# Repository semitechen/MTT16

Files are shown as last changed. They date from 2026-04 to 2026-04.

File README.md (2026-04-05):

**⚠️WARNING⚠️**  
This is a "Work in progress" project.
Read all the documentation before proceeding with development.

# Hardware Tracker MIDI Sequencer

A hardware-style MIDI sequencer designed for DJs and home producers. This device combines tactile control with powerful features to streamline music creation and performance.

---

## Features

### 🎵 Tracks & MIDI Control
- **16 Tracks**: Each track consists of 4 bytes:  
  - **Byte 1**: Type and channel  
  - **Byte 2**: Data byte 1 (note) 
  - **Byte 3**: Data byte 2 (velocity)
  - **Byte 4**: Delay  
- **Editing**: Tracks can be edited and muted via dedicated keypads.

### 🔄 Magnetic Encoder & Sync Control
- **Magnetic Encoder**:  
  - Control track position.  
  - Sync with song tempo "vinyl style".  
  - **Shift Key** under the encoder for alternate functions.  

### 🎚️ Tempo Control
- **Tempo Fader**: Fine-tune playback tempo.  
- **Tempo Modes**:  
  - Select tempo control range (+8, +16, wide) via buttons and LED indicators.

### ⌨️ Keypads & Modes
#### 16-Key Cherry MX Keypad
- **Modes**:  
  - Edit mode (upcoming functionality).  
  - Mute mode: Mute individual tracks.

#### 8-Key Cherry MX Keypad 
| Key | Shift Function | 
|---|---|
| Cue | Play |
| A | Edit |
| B | Mute |
| Scene | New Scene |
| Nudge | Tempo |
| Copy | Paste |
| Delete | Undo |
| OK | Duplicate |

### 📟 Display
- **8x32 7-Segment LED Display**:  
  - Each character is 0.28".  
  - Displays key information across 4 columns in Scene Mode:  
    - Original tempo  
    - Scene  
    - A track  
    - B track  

### 🎛️ Scene Mode
- Use **OK Key** to select a scene and assign it to **Track A** or **Track B** via the **A** and **B** keys.  
- Each scene comprises 16 editable tracks.  
- Select and edit tracks using the **16-Key Keypad** in Edit Mode.  

---

## 📸 Photos
_Add photos here._  

---

## License
This project is licensed under the [Creative Commons Attribution-NonCommercial-ShareAlike 4.0 International License](https://creativecommons.org/licenses/by-nc-sa/4.0/).  

- You are free to build and modify the hardware and software for **non-commercial purposes**.  
- Commercial use of this project is strictly prohibited.

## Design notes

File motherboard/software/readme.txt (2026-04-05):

To program the motherboard (pcb with RP2040 chip), first put the device into divice mode,
then connect the board to the computer using the usb-c port.

Pico sdk should be installed, if you haven't added the --recursive flag while cloning the repo run:
git submodule update --init

To build run the following commands:
mkdir build
cd build
cmake ..
make -j4

Then to flash, inside the build folder, run:
make flash

If this doesn't work:
Hold the usb-boot button while plugging in the usb.
Then copy the motherboard.uf2 file, located in the build folder, to RP2040 external storage device.

The circuit located on the board is pretty much identical to the Rasberry Pi Pico,
so the usage should be the same, apart from the differences caused by the use of usb-c (device mode).

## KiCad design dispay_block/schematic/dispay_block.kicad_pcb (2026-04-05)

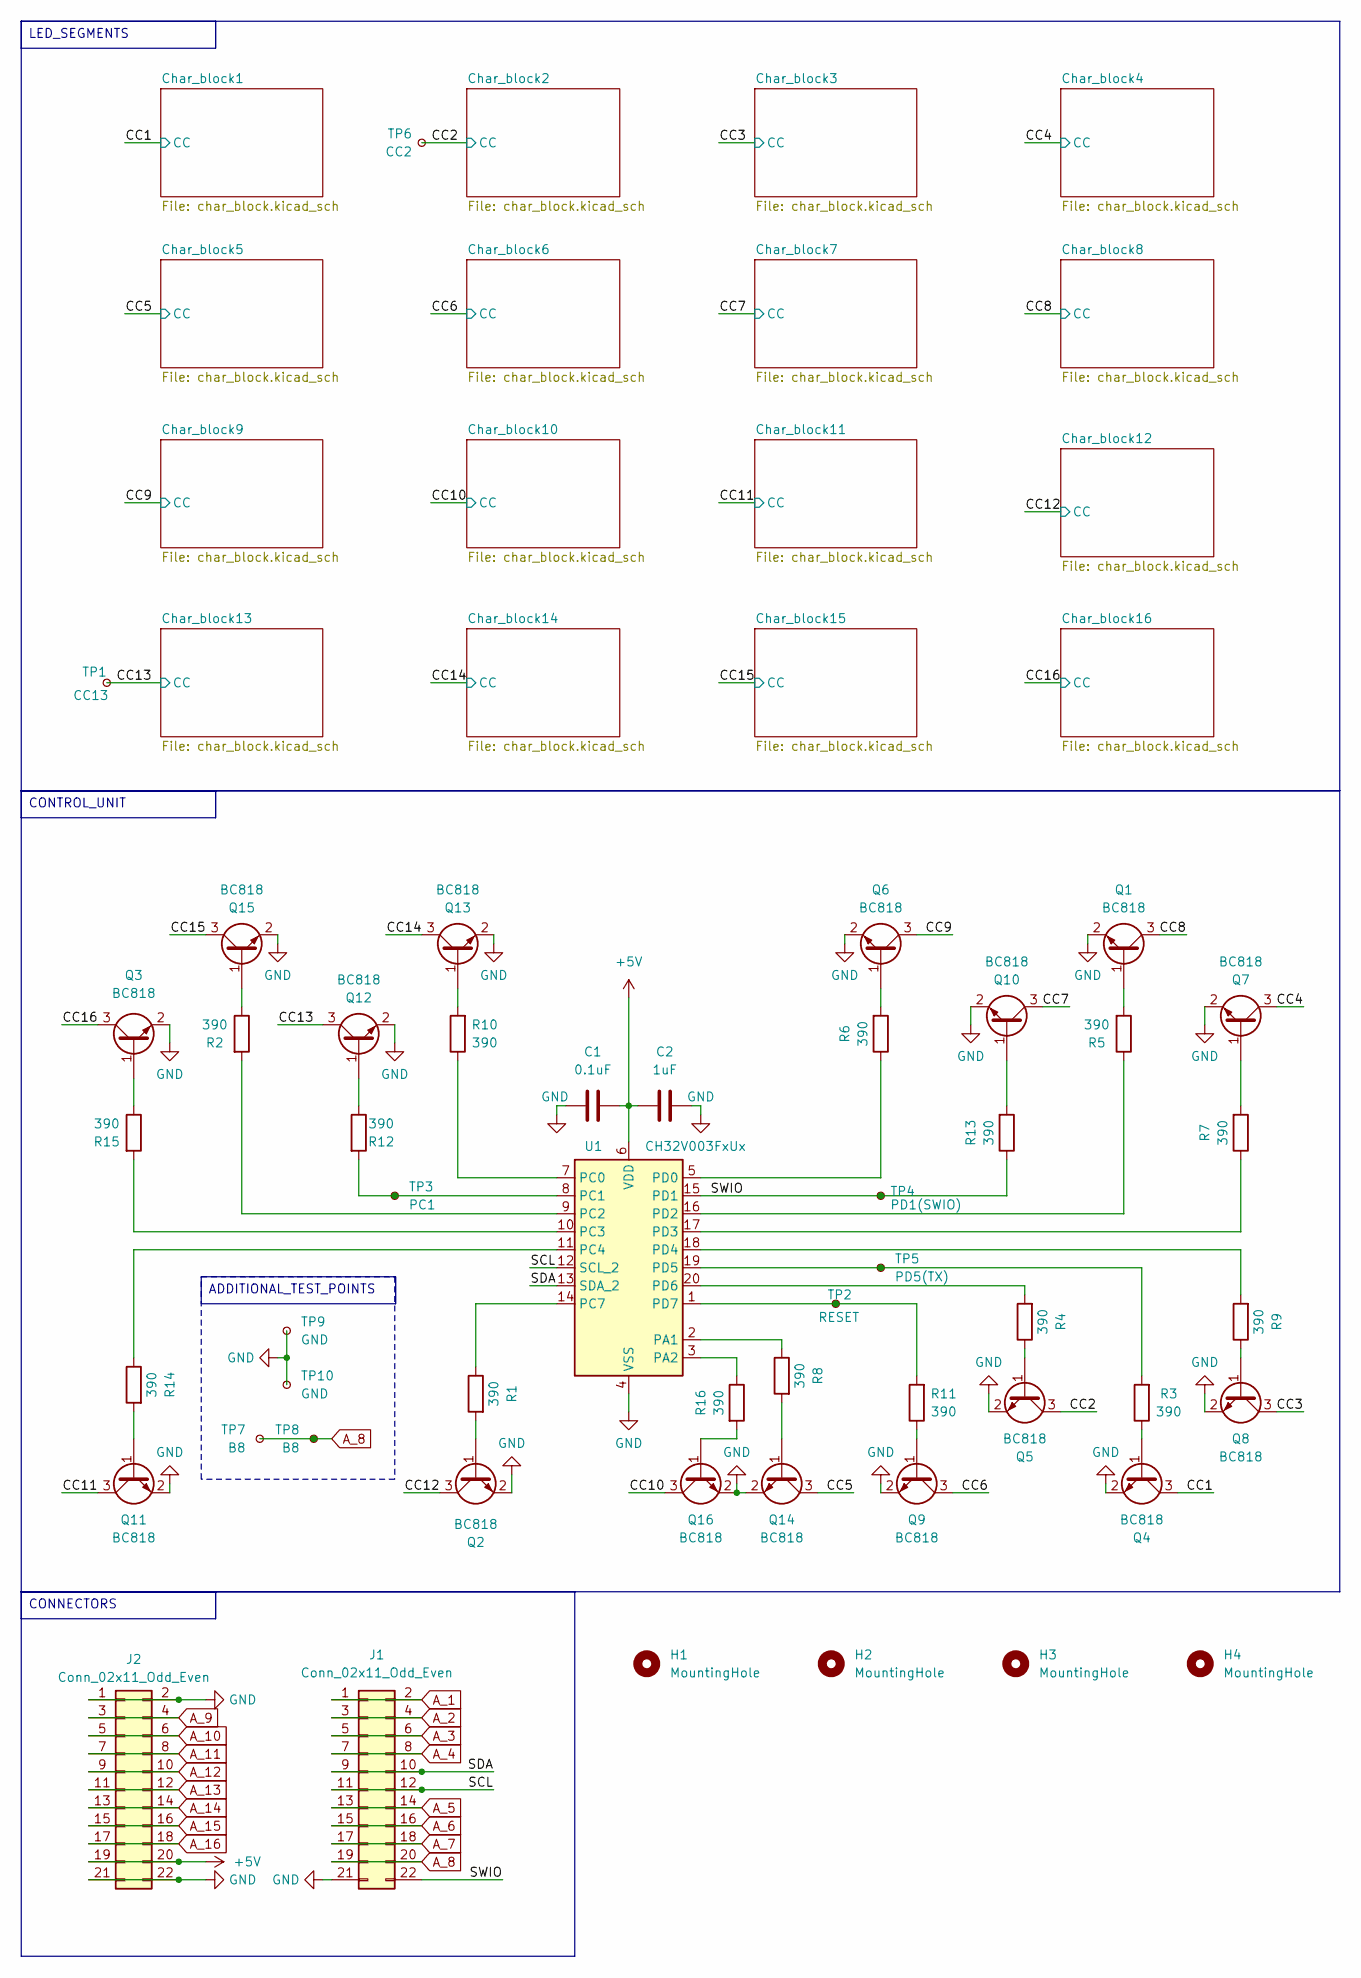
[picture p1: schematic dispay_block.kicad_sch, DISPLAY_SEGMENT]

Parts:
C1: 0.1uF; C_0603_1608Metric
C2: 1uF; C_0603_1608Metric
H1, H2, H3, H4: MountingHole; MountingHole_3.2mm_M3
J1, J2: Conn_02x11_Odd_Even; PinHeader_2x11_P2.54mm_Vertical
Q1, Q2, Q3, Q4, Q5, Q6, Q7, Q8, Q9, Q10, Q11, Q12, Q13, Q14, Q15, Q16: BC818; SOT-23
R1, R2, R3, R4, R5, R6, R7, R8, R9, R10, R11, R12, R13, R14, R15, R16: 390; R_0603_1608Metric
TP1: CC13; TestPoint_Pad_D1.5mm
TP2: RESET; TestPoint_Pad_D1.5mm
TP3: PC1; TestPoint_Pad_D1.5mm
TP4: PD1(SWIO); TestPoint_Pad_D1.5mm
TP5: PD5(TX); TestPoint_Pad_D1.5mm
TP6: CC2; TestPoint_Pad_D1.5mm
TP7, TP8: B8; TestPoint_Pad_D1.5mm
TP9, TP10: GND; TestPoint_Pad_D1.0mm
U1: CH32V003FxUx; QFN-20-1EP_3x3mm_P0.4mm_EP1.65x1.65mm

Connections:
+5V: C1.2, C2.2, J2.19, J2.20, U1.6 (VDD)
/CC1: Q4.3 (C); also elsewhere on the board
/CC2: Q5.3 (C), TP6.1; also elsewhere on the board
/CC3: Q8.3 (C); also elsewhere on the board
/CC4: Q7.3 (C); also elsewhere on the board
/CC5: Q14.3 (C); also elsewhere on the board
/CC6: Q9.3 (C); also elsewhere on the board
/CC7: Q10.3 (C); also elsewhere on the board
/CC8: Q1.3 (C); also elsewhere on the board
/CC9: Q6.3 (C); also elsewhere on the board
/CC10: Q16.3 (C); also elsewhere on the board
/CC11: Q11.3 (C); also elsewhere on the board
/CC12: Q2.3 (C); also elsewhere on the board
/CC13: Q12.3 (C), TP1.1; also elsewhere on the board
/CC14: Q13.3 (C); also elsewhere on the board
/CC15: Q15.3 (C); also elsewhere on the board
/CC16: Q3.3 (C); also elsewhere on the board
/SCL: J1.11, J1.12, U1.12 (SCL_2)
/SDA: J1.9, J1.10, U1.13 (SDA_2)
/SWIO: J1.22, R13.1, TP4.1, U1.15 (PD1)
A_1: J1.1, J1.2; also elsewhere on the board
A_2: J1.3, J1.4; also elsewhere on the board
A_3: J1.5, J1.6; also elsewhere on the board
A_4: J1.7, J1.8; also elsewhere on the board
A_5: J1.13, J1.14; also elsewhere on the board
A_6: J1.15, J1.16; also elsewhere on the board
A_7: J1.17, J1.18; also elsewhere on the board
A_8: J1.19, J1.20, TP7.1, TP8.1; also elsewhere on the board
A_9: J2.3, J2.4; also elsewhere on the board
A_10: J2.5, J2.6; also elsewhere on the board
A_11: J2.7, J2.8; also elsewhere on the board
A_12: J2.9, J2.10; also elsewhere on the board
A_13: J2.11, J2.12; also elsewhere on the board
A_14: J2.13, J2.14; also elsewhere on the board
A_15: J2.15, J2.16; also elsewhere on the board
A_16: J2.17, J2.18; also elsewhere on the board
GND: C1.1, C2.1, J1.21, J2.1, J2.2, J2.21, J2.22, Q1.2 (E), Q2.2 (E), Q3.2 (E), Q4.2 (E), Q5.2 (E), Q6.2 (E), Q7.2 (E), Q8.2 (E), Q9.2 (E), Q10.2 (E), Q11.2 (E), Q12.2 (E), Q13.2 (E), Q14.2 (E), Q15.2 (E), Q16.2 (E), TP9.1, TP10.1, U1.4 (VSS), U1.21 (VSS)
unnamed: Q1.1 (B), R5.2
unnamed: Q2.1 (B), R1.2
unnamed: Q3.1 (B), R15.1
unnamed: Q4.1 (B), R3.1
unnamed: Q5.1 (B), R4.1
unnamed: Q6.1 (B), R6.2
unnamed: Q7.1 (B), R7.2
unnamed: Q8.1 (B), R9.1
unnamed: Q9.1 (B), R11.1
unnamed: Q10.1 (B), R13.2
unnamed: Q11.1 (B), R14.2
unnamed: Q12.1 (B), R12.1
unnamed: Q13.1 (B), R10.2
unnamed: Q14.1 (B), R8.2
unnamed: Q15.1 (B), R2.1
unnamed: Q16.1 (B), R16.2
unnamed: R8.1, U1.2 (PA1)
unnamed: R16.1, U1.3 (PA2)
unnamed: R10.1, U1.7 (PC0)
unnamed: R12.2, TP3.1, U1.8 (PC1)
unnamed: R2.2, U1.9 (PC2)
unnamed: R15.2, U1.10 (PC3)
unnamed: R14.1, U1.11 (PC4)
unnamed: R1.1, U1.14 (PC7)
unnamed: R6.1, U1.5 (PD0)
unnamed: R5.1, U1.16 (PD2)
unnamed: R7.1, U1.17 (PD3)
unnamed: R9.2, U1.18 (PD4)
unnamed: R3.2, TP5.1, U1.19 (PD5)
unnamed: R4.2, U1.20 (PD6)
unnamed: R11.2, TP2.1, U1.1 (PD7)

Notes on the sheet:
LED_SEGMENTS
CONTROL_UNIT
CONNECTORS
ADDITIONAL_TEST_POINTS

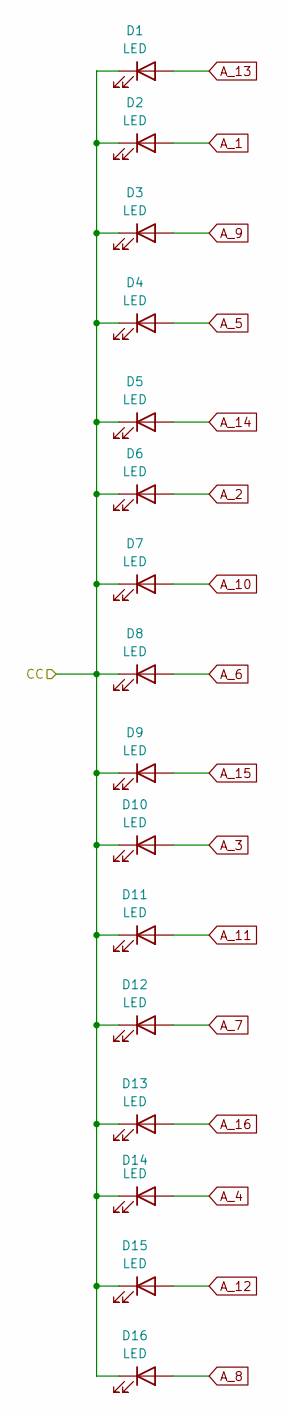
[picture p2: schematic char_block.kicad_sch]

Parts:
D1, D2, D3, D4, D5, D6, D7, D8, D9, D10, D11, D12, D13, D14, D15, D16: LED; LED_0603_1608Metric

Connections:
/CC1: D1.1 (K), D2.1 (K), D3.1 (K), D4.1 (K), D5.1 (K), D6.1 (K), D7.1 (K), D8.1 (K), D9.1 (K), D10.1 (K), D11.1 (K), D12.1 (K), D13.1 (K), D14.1 (K), D15.1 (K), D16.1 (K); also elsewhere on the board
A_1: D2.2 (A); also elsewhere on the board
A_2: D6.2 (A); also elsewhere on the board
A_3: D10.2 (A); also elsewhere on the board
A_4: D14.2 (A); also elsewhere on the board
A_5: D4.2 (A); also elsewhere on the board
A_6: D8.2 (A); also elsewhere on the board
A_7: D12.2 (A); also elsewhere on the board
A_8: D16.2 (A); also elsewhere on the board
A_9: D3.2 (A); also elsewhere on the board
A_10: D7.2 (A); also elsewhere on the board
A_11: D11.2 (A); also elsewhere on the board
A_12: D15.2 (A); also elsewhere on the board
A_13: D1.2 (A); also elsewhere on the board
A_14: D5.2 (A); also elsewhere on the board
A_15: D9.2 (A); also elsewhere on the board
A_16: D13.2 (A); also elsewhere on the board

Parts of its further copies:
D17, D18, D19, D20, D21, D22, D23, D24, D25, D26, D27, D28, D29, D30, D31, D32, D33, D34, D35, D36, D37, D38, D39, D40, D41, D42, D43, D44, D45, D46, D47, D48, D49, D50, D51, D52, D53, D54, D55, D56, D57, D58, D59, D60, D61, D62, D63, D64, D65, D66, D67, D68, D69, D70, D71, D72, D73, D74, D75, D76, D77, D78, D79, D80, D81, D82, D83, D84, D85, D86, D87, D88, D89, D90, D91, D92, D93, D94, D95, D96, D97, D98, D99, D100, D101, D102, D103, D104, D105, D106, D107, D108, D109, D110, D111, D112, D113, D114, D115, D116, D117, D118, D119, D120, D121, D122, D123, D124, D125, D126, D127, D128, D129, D130, D131, D132, D133, D134, D135, D136, D137, D138, D139, D140, D141, D142, D143, D144, D145, D146, D147, D148, D149, D150, D151, D152, D153, D154, D155, D156, D157, D158, D159, D160, D161, D162, D163, D164, D165, D166, D167, D168, D169, D170, D171, D172, D173, D174, D175, D176, D177, D178, D179, D180, D181, D182, D183, D184, D185, D186, D187, D188, D189, D190, D191, D192, D193, D194, D195, D196, D197, D198, D199, D200, D201, D202, D203, D204, D205, D206, D207, D208, D209, D210, D211, D212, D213, D214, D215, D216, D217, D218, D219, D220, D221, D222, D223, D224, D225, D226, D227, D228, D229, D230, D231, D232, D233, D234, D235, D236, D237, D238, D239, D240, D241, D242, D243, D244, D245, D246, D247, D248, D249, D250, D251, D252, D253, D254, D255, D256: LED; LED_0603_1608Metric

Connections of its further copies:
/CC2: D17.1 (K), D18.1 (K), D19.1 (K), D20.1 (K), D21.1 (K), D22.1 (K), D23.1 (K), D24.1 (K), D25.1 (K), D26.1 (K), D27.1 (K), D28.1 (K), D29.1 (K), D30.1 (K), D31.1 (K), D32.1 (K); also elsewhere on the board
/CC3: D33.1 (K), D34.1 (K), D35.1 (K), D36.1 (K), D37.1 (K), D38.1 (K), D39.1 (K), D40.1 (K), D41.1 (K), D42.1 (K), D43.1 (K), D44.1 (K), D45.1 (K), D46.1 (K), D47.1 (K), D48.1 (K); also elsewhere on the board
/CC4: D49.1 (K), D50.1 (K), D51.1 (K), D52.1 (K), D53.1 (K), D54.1 (K), D55.1 (K), D56.1 (K), D57.1 (K), D58.1 (K), D59.1 (K), D60.1 (K), D61.1 (K), D62.1 (K), D63.1 (K), D64.1 (K); also elsewhere on the board
/CC5: D65.1 (K), D66.1 (K), D67.1 (K), D68.1 (K), D69.1 (K), D70.1 (K), D71.1 (K), D72.1 (K), D73.1 (K), D74.1 (K), D75.1 (K), D76.1 (K), D77.1 (K), D78.1 (K), D79.1 (K), D80.1 (K); also elsewhere on the board
/CC6: D81.1 (K), D82.1 (K), D83.1 (K), D84.1 (K), D85.1 (K), D86.1 (K), D87.1 (K), D88.1 (K), D89.1 (K), D90.1 (K), D91.1 (K), D92.1 (K), D93.1 (K), D94.1 (K), D95.1 (K), D96.1 (K); also elsewhere on the board
/CC7: D97.1 (K), D98.1 (K), D99.1 (K), D100.1 (K), D101.1 (K), D102.1 (K), D103.1 (K), D104.1 (K), D105.1 (K), D106.1 (K), D107.1 (K), D108.1 (K), D109.1 (K), D110.1 (K), D111.1 (K), D112.1 (K); also elsewhere on the board
/CC8: D113.1 (K), D114.1 (K), D115.1 (K), D116.1 (K), D117.1 (K), D118.1 (K), D119.1 (K), D120.1 (K), D121.1 (K), D122.1 (K), D123.1 (K), D124.1 (K), D125.1 (K), D126.1 (K), D127.1 (K), D128.1 (K); also elsewhere on the board
/CC9: D129.1 (K), D130.1 (K), D131.1 (K), D132.1 (K), D133.1 (K), D134.1 (K), D135.1 (K), D136.1 (K), D137.1 (K), D138.1 (K), D139.1 (K), D140.1 (K), D141.1 (K), D142.1 (K), D143.1 (K), D144.1 (K); also elsewhere on the board
/CC10: D145.1 (K), D146.1 (K), D147.1 (K), D148.1 (K), D149.1 (K), D150.1 (K), D151.1 (K), D152.1 (K), D153.1 (K), D154.1 (K), D155.1 (K), D156.1 (K), D157.1 (K), D158.1 (K), D159.1 (K), D160.1 (K); also elsewhere on the board
/CC11: D161.1 (K), D162.1 (K), D163.1 (K), D164.1 (K), D165.1 (K), D166.1 (K), D167.1 (K), D168.1 (K), D169.1 (K), D170.1 (K), D171.1 (K), D172.1 (K), D173.1 (K), D174.1 (K), D175.1 (K), D176.1 (K); also elsewhere on the board
/CC12: D177.1 (K), D178.1 (K), D179.1 (K), D180.1 (K), D181.1 (K), D182.1 (K), D183.1 (K), D184.1 (K), D185.1 (K), D186.1 (K), D187.1 (K), D188.1 (K), D189.1 (K), D190.1 (K), D191.1 (K), D192.1 (K); also elsewhere on the board
/CC13: D193.1 (K), D194.1 (K), D195.1 (K), D196.1 (K), D197.1 (K), D198.1 (K), D199.1 (K), D200.1 (K), D201.1 (K), D202.1 (K), D203.1 (K), D204.1 (K), D205.1 (K), D206.1 (K), D207.1 (K), D208.1 (K); also elsewhere on the board
/CC14: D209.1 (K), D210.1 (K), D211.1 (K), D212.1 (K), D213.1 (K), D214.1 (K), D215.1 (K), D216.1 (K), D217.1 (K), D218.1 (K), D219.1 (K), D220.1 (K), D221.1 (K), D222.1 (K), D223.1 (K), D224.1 (K); also elsewhere on the board
/CC15: D225.1 (K), D226.1 (K), D227.1 (K), D228.1 (K), D229.1 (K), D230.1 (K), D231.1 (K), D232.1 (K), D233.1 (K), D234.1 (K), D235.1 (K), D236.1 (K), D237.1 (K), D238.1 (K), D239.1 (K), D240.1 (K); also elsewhere on the board
/CC16: D241.1 (K), D242.1 (K), D243.1 (K), D244.1 (K), D245.1 (K), D246.1 (K), D247.1 (K), D248.1 (K), D249.1 (K), D250.1 (K), D251.1 (K), D252.1 (K), D253.1 (K), D254.1 (K), D255.1 (K), D256.1 (K); also elsewhere on the board
A_1: D18.2 (A), D34.2 (A), D50.2 (A), D66.2 (A), D82.2 (A), D98.2 (A), D114.2 (A), D130.2 (A), D146.2 (A), D162.2 (A), D178.2 (A), D194.2 (A), D210.2 (A), D226.2 (A), D242.2 (A); also elsewhere on the board
A_2: D22.2 (A), D38.2 (A), D54.2 (A), D70.2 (A), D86.2 (A), D102.2 (A), D118.2 (A), D134.2 (A), D150.2 (A), D166.2 (A), D182.2 (A), D198.2 (A), D214.2 (A), D230.2 (A), D246.2 (A); also elsewhere on the board
A_3: D26.2 (A), D42.2 (A), D58.2 (A), D74.2 (A), D90.2 (A), D106.2 (A), D122.2 (A), D138.2 (A), D154.2 (A), D170.2 (A), D186.2 (A), D202.2 (A), D218.2 (A), D234.2 (A), D250.2 (A); also elsewhere on the board
A_4: D30.2 (A), D46.2 (A), D62.2 (A), D78.2 (A), D94.2 (A), D110.2 (A), D126.2 (A), D142.2 (A), D158.2 (A), D174.2 (A), D190.2 (A), D206.2 (A), D222.2 (A), D238.2 (A), D254.2 (A); also elsewhere on the board
A_5: D20.2 (A), D36.2 (A), D52.2 (A), D68.2 (A), D84.2 (A), D100.2 (A), D116.2 (A), D132.2 (A), D148.2 (A), D164.2 (A), D180.2 (A), D196.2 (A), D212.2 (A), D228.2 (A), D244.2 (A); also elsewhere on the board
A_6: D24.2 (A), D40.2 (A), D56.2 (A), D72.2 (A), D88.2 (A), D104.2 (A), D120.2 (A), D136.2 (A), D152.2 (A), D168.2 (A), D184.2 (A), D200.2 (A), D216.2 (A), D232.2 (A), D248.2 (A); also elsewhere on the board
A_7: D28.2 (A), D44.2 (A), D60.2 (A), D76.2 (A), D92.2 (A), D108.2 (A), D124.2 (A), D140.2 (A), D156.2 (A), D172.2 (A), D188.2 (A), D204.2 (A), D220.2 (A), D236.2 (A), D252.2 (A); also elsewhere on the board
A_8: D32.2 (A), D48.2 (A), D64.2 (A), D80.2 (A), D96.2 (A), D112.2 (A), D128.2 (A), D144.2 (A), D160.2 (A), D176.2 (A), D192.2 (A), D208.2 (A), D224.2 (A), D240.2 (A), D256.2 (A); also elsewhere on the board
A_9: D19.2 (A), D35.2 (A), D51.2 (A), D67.2 (A), D83.2 (A), D99.2 (A), D115.2 (A), D131.2 (A), D147.2 (A), D163.2 (A), D179.2 (A), D195.2 (A), D211.2 (A), D227.2 (A), D243.2 (A); also elsewhere on the board
A_10: D23.2 (A), D39.2 (A), D55.2 (A), D71.2 (A), D87.2 (A), D103.2 (A), D119.2 (A), D135.2 (A), D151.2 (A), D167.2 (A), D183.2 (A), D199.2 (A), D215.2 (A), D231.2 (A), D247.2 (A); also elsewhere on the board
A_11: D27.2 (A), D43.2 (A), D59.2 (A), D75.2 (A), D91.2 (A), D107.2 (A), D123.2 (A), D139.2 (A), D155.2 (A), D171.2 (A), D187.2 (A), D203.2 (A), D219.2 (A), D235.2 (A), D251.2 (A); also elsewhere on the board
A_12: D31.2 (A), D47.2 (A), D63.2 (A), D79.2 (A), D95.2 (A), D111.2 (A), D127.2 (A), D143.2 (A), D159.2 (A), D175.2 (A), D191.2 (A), D207.2 (A), D223.2 (A), D239.2 (A), D255.2 (A); also elsewhere on the board
A_13: D17.2 (A), D33.2 (A), D49.2 (A), D65.2 (A), D81.2 (A), D97.2 (A), D113.2 (A), D129.2 (A), D145.2 (A), D161.2 (A), D177.2 (A), D193.2 (A), D209.2 (A), D225.2 (A), D241.2 (A); also elsewhere on the board
A_14: D21.2 (A), D37.2 (A), D53.2 (A), D69.2 (A), D85.2 (A), D101.2 (A), D117.2 (A), D133.2 (A), D149.2 (A), D165.2 (A), D181.2 (A), D197.2 (A), D213.2 (A), D229.2 (A), D245.2 (A); also elsewhere on the board
A_15: D25.2 (A), D41.2 (A), D57.2 (A), D73.2 (A), D89.2 (A), D105.2 (A), D121.2 (A), D137.2 (A), D153.2 (A), D169.2 (A), D185.2 (A), D201.2 (A), D217.2 (A), D233.2 (A), D249.2 (A); also elsewhere on the board
A_16: D29.2 (A), D45.2 (A), D61.2 (A), D77.2 (A), D93.2 (A), D109.2 (A), D125.2 (A), D141.2 (A), D157.2 (A), D173.2 (A), D189.2 (A), D205.2 (A), D221.2 (A), D237.2 (A), D253.2 (A); also elsewhere on the board

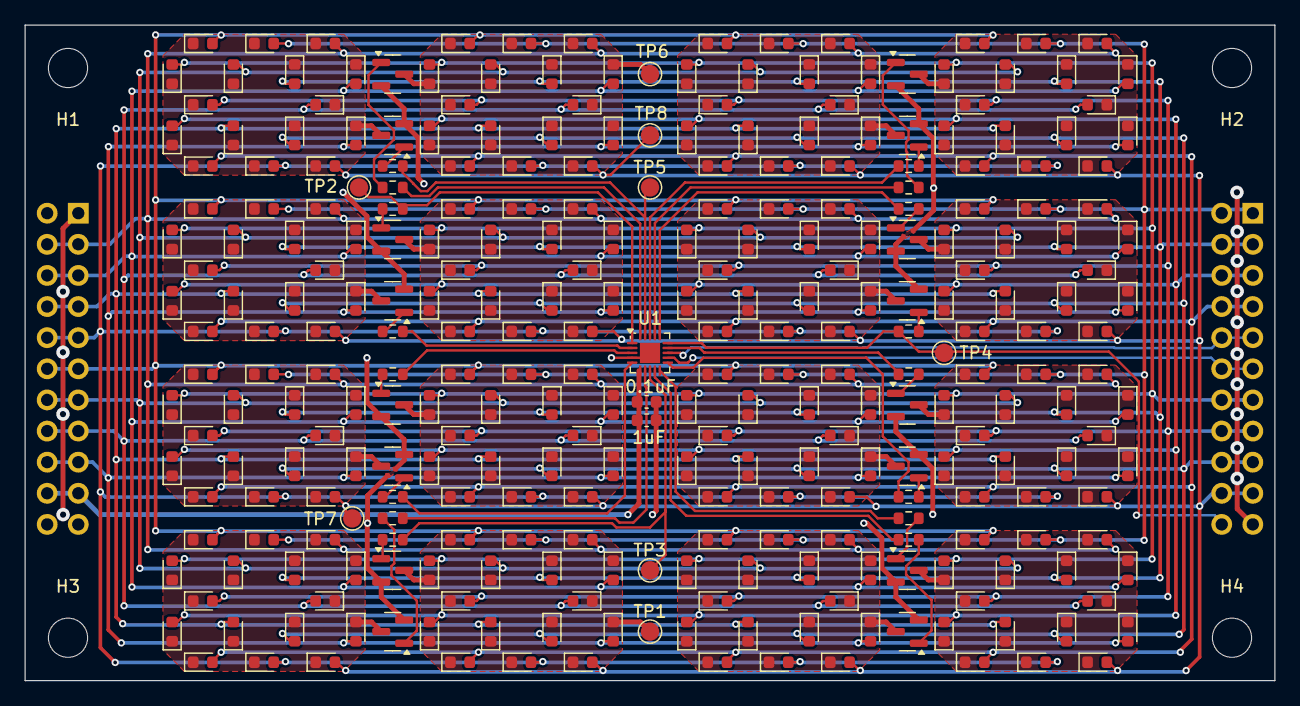
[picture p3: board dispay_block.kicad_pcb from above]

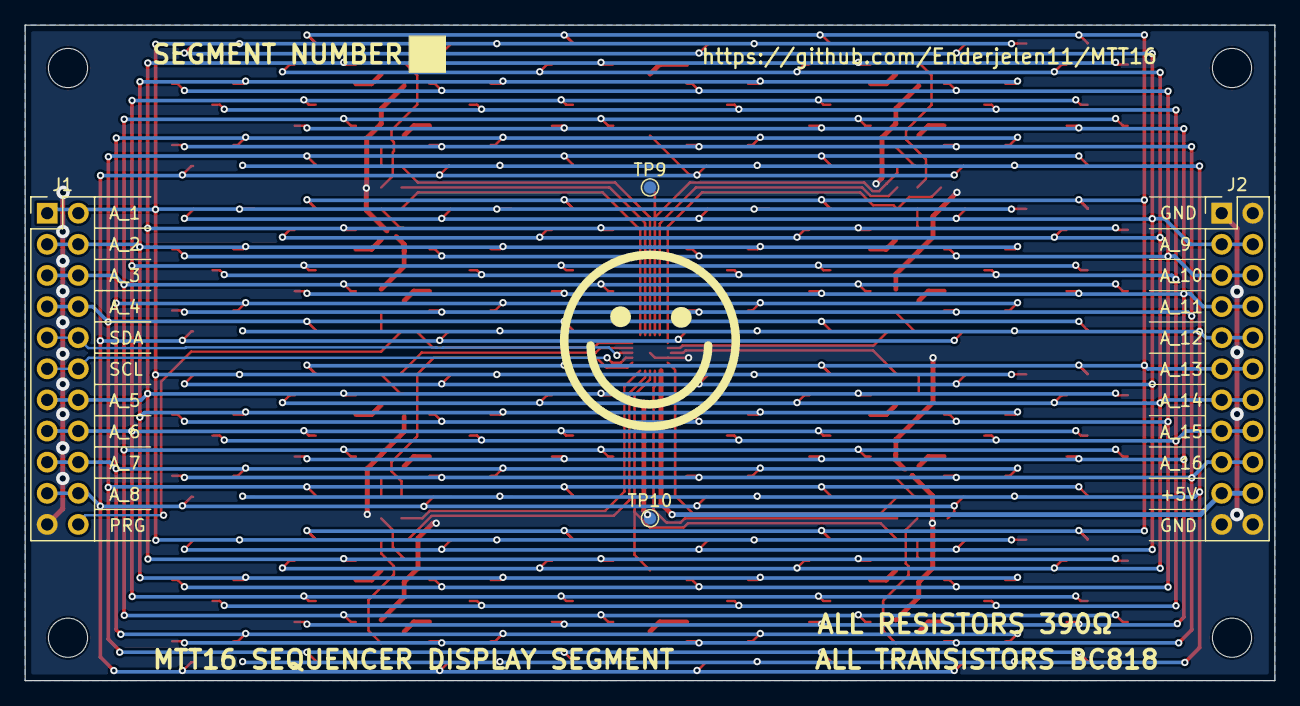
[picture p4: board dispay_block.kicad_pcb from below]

Board: 2 copper layers, 102.0 x 53.5 mm, 307 parts (4 on the bottom side), 68 nets.

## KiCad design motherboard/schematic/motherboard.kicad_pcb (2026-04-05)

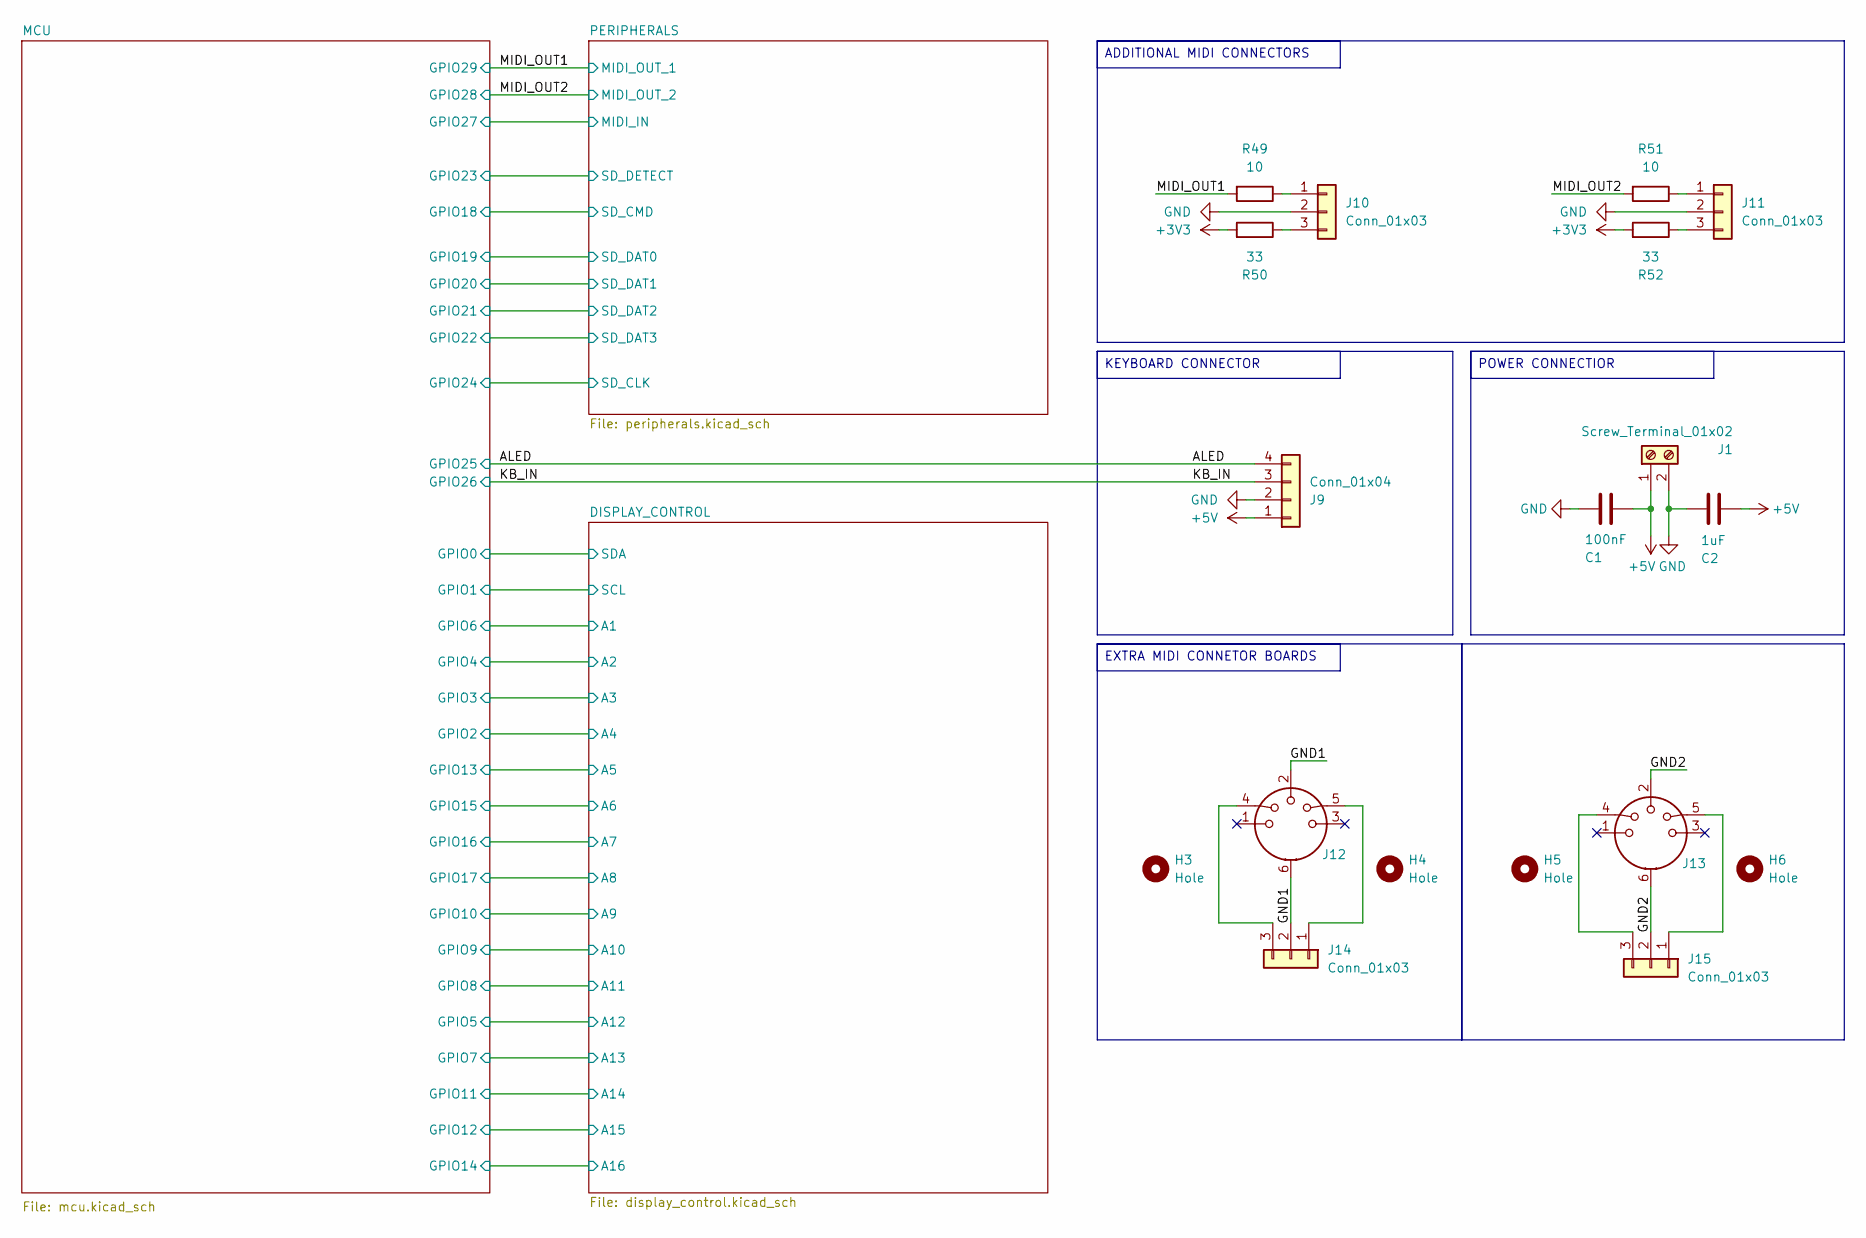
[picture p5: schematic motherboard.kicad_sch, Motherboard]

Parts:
C1: 100nF; C_0603_1608Metric
C2: 1uF; C_0603_1608Metric
H3, H4, H5, H6: Hole; MountingHole_3.2mm_M3
J1: Screw_Terminal_01x02; TerminalBlock_Phoenix_MKDS-1,5-2_1x02_P5.00mm_Horizontal
J9: Conn_01x04; PinHeader_1x04_P2.54mm_Vertical
J10, J11, J14, J15: Conn_01x03; PinHeader_1x03_P2.54mm_Vertical
J12, J13: MIDI_DIN5
R49, R51: 10; R_0603_1608Metric
R50, R52: 33; R_0603_1608Metric

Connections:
+3V3: R50.2, R52.2; also elsewhere on the board
+5V: C1.2, C2.2, J1.1, J9.1; also elsewhere on the board
/ALED: J9.4; also elsewhere on the board
/GND1: J12.2, J12.6, J14.2
/GND2: J13.2, J13.6, J15.2
/KB_IN: J9.3; also elsewhere on the board
/MIDI_OUT1: R49.2; also elsewhere on the board
/MIDI_OUT2: R51.2; also elsewhere on the board
GND: C1.1, C2.1, J1.2, J9.2, J10.2, J11.2; also elsewhere on the board
unnamed: J10.1, R49.1
unnamed: J10.3, R50.1
unnamed: J11.1, R51.1
unnamed: J11.3, R52.1
unnamed: J12.5, J14.1
unnamed: J12.4, J14.3
unnamed: J13.5, J15.1
unnamed: J13.4, J15.3

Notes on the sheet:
KEYBOARD CONNECTOR
ADDITIONAL MIDI CONNECTORS
POWER CONNECTIOR
EXTRA MIDI CONNETOR BOARDS

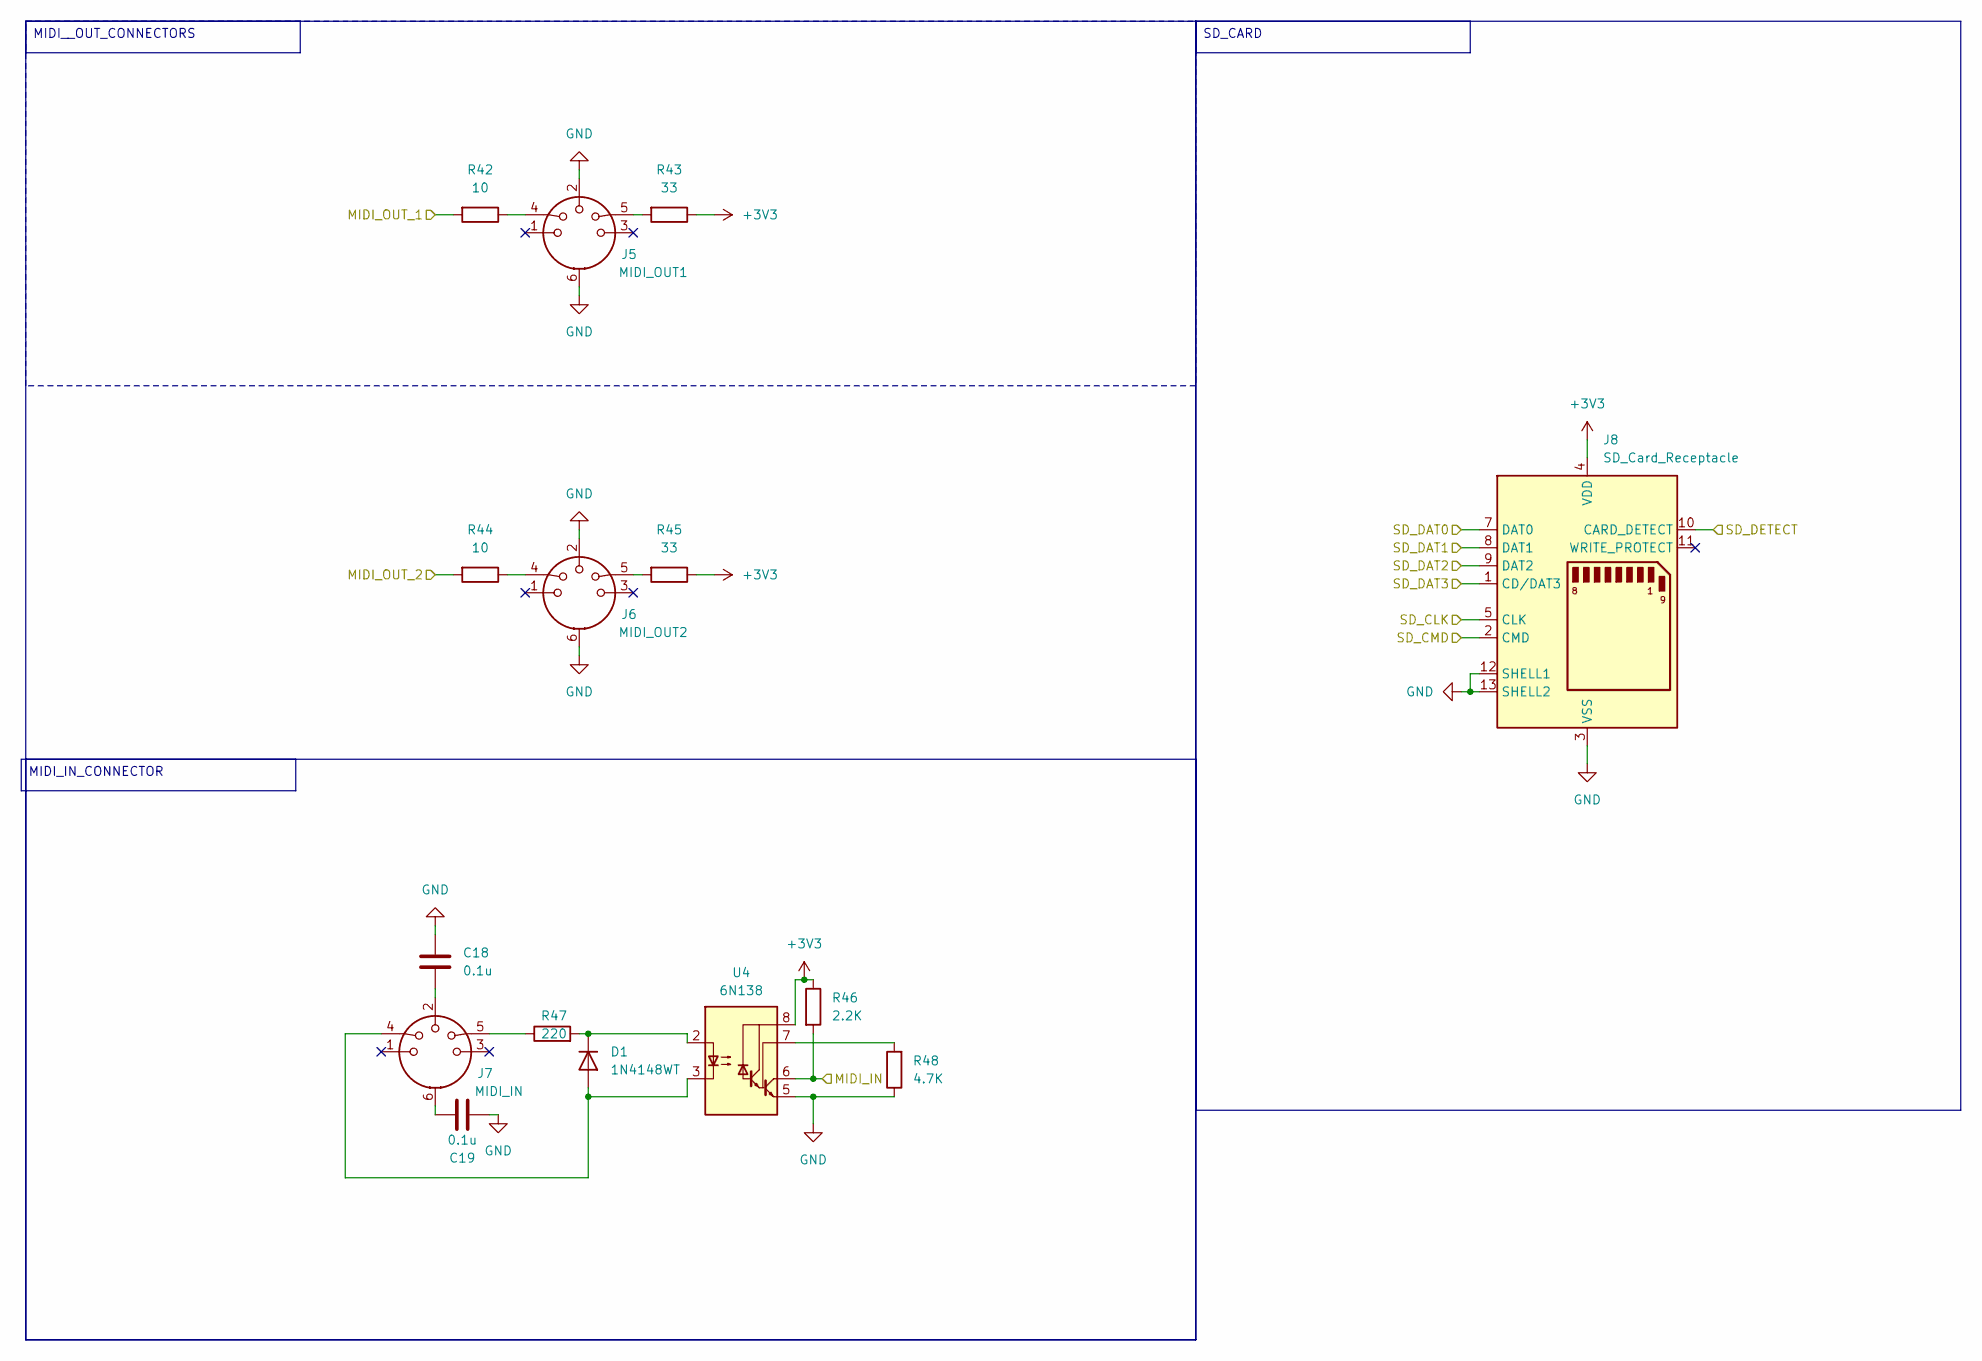
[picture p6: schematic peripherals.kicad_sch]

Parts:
C18, C19: 0.1u; C_0603_1608Metric
D1: 1N4148WT; D_SOD-523
J5: MIDI_OUT1; MIDI_DIN5
J6: MIDI_OUT2; MIDI_DIN5
J7: MIDI_IN; MIDI_DIN5
J8: SD_Card_Receptacle; SD_Kyocera_145638009511859+
R42, R44: 10; R_0603_1608Metric
R43, R45: 33; R_0603_1608Metric
R46: 2.2K; R_0603_1608Metric
R47: 220; R_0603_1608Metric
R48: 4.7K; R_0603_1608Metric
U4: 6N138; SMDIP-8_W9.53mm

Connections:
+3V3: J8.4 (VDD), R43.1, R45.1, R46.1, U4.8 (VCC); also elsewhere on the board
/MCU/GPIO18: J8.2 (CMD); also elsewhere on the board
/MCU/GPIO19: J8.7 (DAT0); also elsewhere on the board
/MCU/GPIO20: J8.8 (DAT1); also elsewhere on the board
/MCU/GPIO21: J8.9 (DAT2); also elsewhere on the board
/MCU/GPIO22: J8.1 (CD/DAT3); also elsewhere on the board
/MCU/GPIO23: J8.10 (CARD_DETECT); also elsewhere on the board
/MCU/GPIO24: J8.5 (CLK); also elsewhere on the board
/MCU/GPIO27: R46.2, U4.6 (VO2); also elsewhere on the board
/MIDI_OUT1: R42.2; also elsewhere on the board
/MIDI_OUT2: R44.2; also elsewhere on the board
GND: C18.1, C19.2, J5.2, J5.6, J6.2, J6.6, J8.3 (VSS), J8.6 (VSS), J8.12 (SHELL1), J8.13 (SHELL2), R48.1, U4.5 (GND); also elsewhere on the board
unnamed: C18.2, J7.2
unnamed: C19.1, J7.6
unnamed: D1.2 (A), J7.4, U4.3 (C2)
unnamed: D1.1 (K), R47.2, U4.2 (C1)
unnamed: J5.4, R42.1
unnamed: J5.5, R43.2
unnamed: J6.4, R44.1
unnamed: J6.5, R45.2
unnamed: J7.5, R47.1
unnamed: R48.2, U4.7 (VO1)

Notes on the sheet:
SD_CARD
MIDI_IN_CONNECTOR
MIDI__OUT_CONNECTORS

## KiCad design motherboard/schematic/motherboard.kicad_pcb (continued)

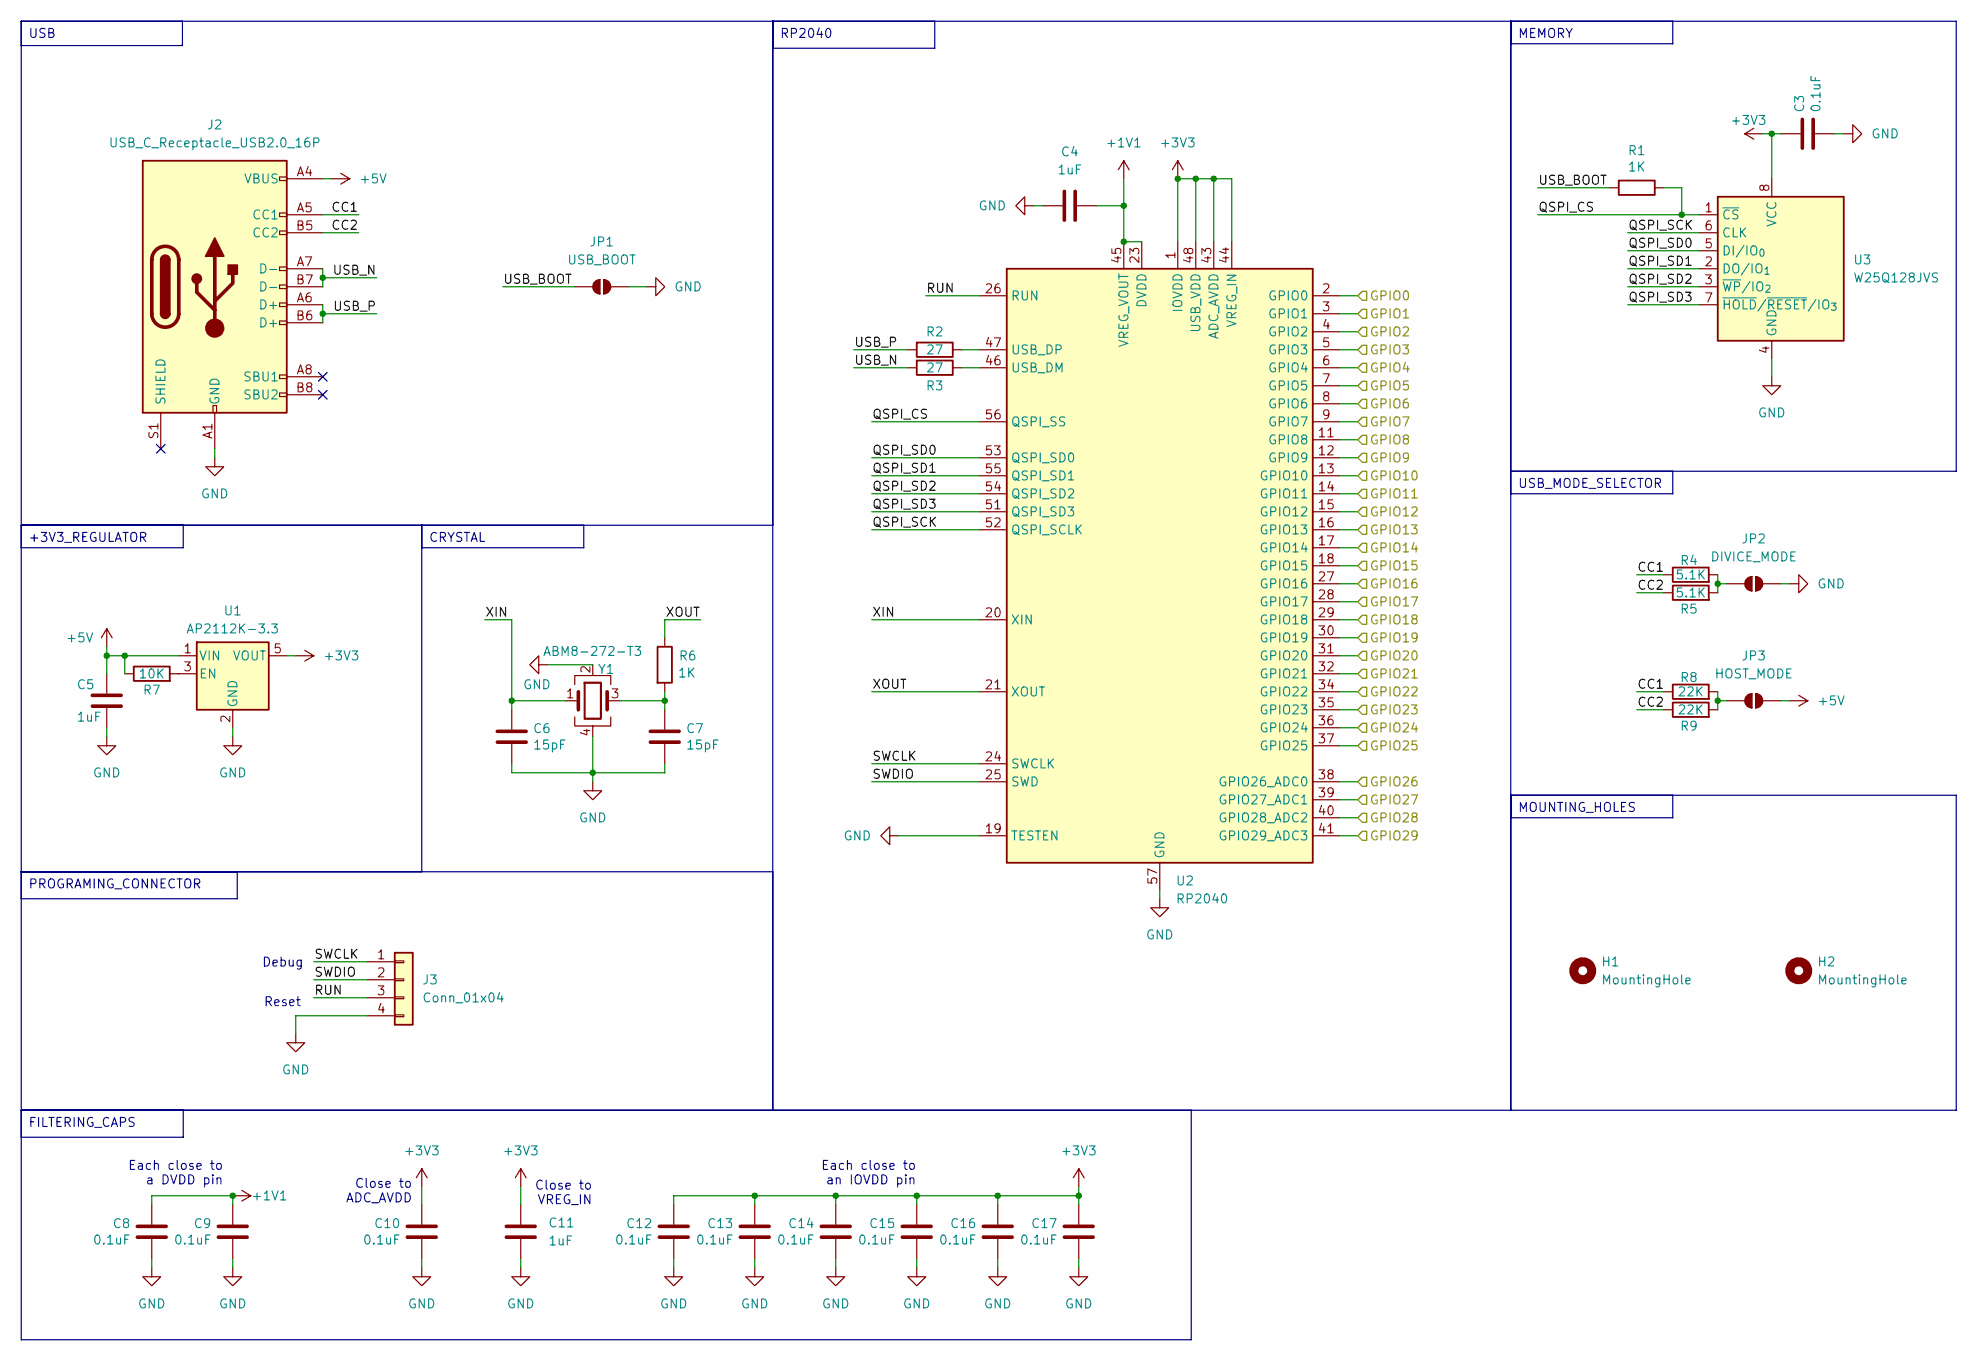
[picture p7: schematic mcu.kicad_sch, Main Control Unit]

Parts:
C3, C8, C9, C10, C12, C13, C14, C15, C16, C17: 0.1uF; C_0603_1608Metric; Digi-Key_PN 311-1344-1-ND
C4, C5, C11: 1uF; C_0603_1608Metric
C6, C7: 15pF; C_0603_1608Metric; Digi-Key_PN 311-1063-1-ND
H1, H2: MountingHole; MountingHole_3.2mm_M3
J2: USB_C_Receptacle_USB2.0_16P; USB_C_Receptacle_GCT_USB4110
J3: Conn_01x04; PinHeader_2x02_P2.54mm_Vertical
JP1: USB_BOOT; SolderJumper-2_P1.3mm_Open_Pad1.0x1.5mm
JP2: DIVICE_MODE; SolderJumper-2_P1.3mm_Open_Pad1.0x1.5mm
JP3: HOST_MODE; SolderJumper-2_P1.3mm_Open_Pad1.0x1.5mm
R1, R6: 1K; R_0603_1608Metric; Digi-Key_PN 311-1.00KHRCT-ND
R2, R3: 27; R_0603_1608Metric
R4, R5: 5.1K; R_0603_1608Metric
R7: 10K; R_0603_1608Metric
R8, R9: 22K; R_0603_1608Metric
U1: AP2112K-3.3; SOT-23-5
U2: RP2040; QFN-56-1EP_7x7mm_P0.4mm_EP3.2x3.2mm
U3: W25Q128JVS; SOIC-8_5.3x5.3mm_P1.27mm
Y1: ABM8-272-T3; Crystal_SMD_Abracon_ABM8G-4Pin_3.2x2.5mm

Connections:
+1V1: C4.2, C8.1, C9.1, U2.23 (DVDD), U2.45 (VREG_VOUT), U2.50 (DVDD)
+3V3: C3.1, C10.1, C11.1, C12.1, C13.1, C14.1, C15.1, C16.1, C17.1, U1.5 (VOUT), U2.1 (IOVDD), U2.10 (IOVDD), U2.22 (IOVDD), U2.33 (IOVDD), U2.42 (IOVDD), U2.43 (ADC_AVDD), U2.44 (VREG_IN), U2.48 (USB_VDD), U2.49 (IOVDD), U3.8 (VCC); also elsewhere on the board
+5V: C5.1, J2.A4 (VBUS), J2.A9 (VBUS), J2.B4 (VBUS), J2.B9 (VBUS), JP3.2 (B), R7.1, U1.1 (VIN); also elsewhere on the board
/ALED: U2.37 (GPIO25); also elsewhere on the board
/DISPLAY_CONTROL/A1: U2.8 (GPIO6); also elsewhere on the board
/DISPLAY_CONTROL/A2: U2.6 (GPIO4); also elsewhere on the board
/DISPLAY_CONTROL/A3: U2.5 (GPIO3); also elsewhere on the board
/DISPLAY_CONTROL/A4: U2.4 (GPIO2); also elsewhere on the board
/DISPLAY_CONTROL/A5: U2.16 (GPIO13); also elsewhere on the board
/DISPLAY_CONTROL/A6: U2.18 (GPIO15); also elsewhere on the board
/DISPLAY_CONTROL/A7: U2.27 (GPIO16); also elsewhere on the board
/DISPLAY_CONTROL/A8: U2.28 (GPIO17); also elsewhere on the board
/DISPLAY_CONTROL/A9: U2.13 (GPIO10); also elsewhere on the board
/DISPLAY_CONTROL/A10: U2.12 (GPIO9); also elsewhere on the board
/DISPLAY_CONTROL/A11: U2.11 (GPIO8); also elsewhere on the board
/DISPLAY_CONTROL/A12: U2.7 (GPIO5); also elsewhere on the board
/DISPLAY_CONTROL/A13: U2.9 (GPIO7); also elsewhere on the board
/DISPLAY_CONTROL/A14: U2.14 (GPIO11); also elsewhere on the board
/DISPLAY_CONTROL/A15: U2.15 (GPIO12); also elsewhere on the board
/DISPLAY_CONTROL/A16: U2.17 (GPIO14); also elsewhere on the board
/DISPLAY_CONTROL/SCL: U2.3 (GPIO1); also elsewhere on the board
/DISPLAY_CONTROL/SDA: U2.2 (GPIO0); also elsewhere on the board
/KB_IN: U2.38 (GPIO26_ADC0); also elsewhere on the board
/MCU/CC1: J2.A5 (CC1), R4.1, R8.1
/MCU/CC2: J2.B5 (CC2), R5.1, R9.1
/MCU/GPIO18: U2.29 (GPIO18); also elsewhere on the board
/MCU/GPIO19: U2.30 (GPIO19); also elsewhere on the board
/MCU/GPIO20: U2.31 (GPIO20); also elsewhere on the board
/MCU/GPIO21: U2.32 (GPIO21); also elsewhere on the board
/MCU/GPIO22: U2.34 (GPIO22); also elsewhere on the board
/MCU/GPIO23: U2.35 (GPIO23); also elsewhere on the board
/MCU/GPIO24: U2.36 (GPIO24); also elsewhere on the board
/MCU/GPIO27: U2.39 (GPIO27_ADC1); also elsewhere on the board
/MCU/QSPI_CS: R1.1, U2.56 (QSPI_SS), U3.1 (~CS)
/MCU/QSPI_SCK: U2.52 (QSPI_SCLK), U3.6 (CLK)
/MCU/QSPI_SD0: U2.53 (QSPI_SD0), U3.5 (DI/IO_{0})
/MCU/QSPI_SD1: U2.55 (QSPI_SD1), U3.2 (DO/IO_{1})
/MCU/QSPI_SD2: U2.54 (QSPI_SD2), U3.3 (~WP/IO_{2})
/MCU/QSPI_SD3: U2.51 (QSPI_SD3), U3.7 (~HOLD/~RESET/IO_{3})
/MCU/RUN: J3.3, U2.26 (RUN)
/MCU/SWCLK: J3.1, U2.24 (SWCLK)
/MCU/SWDIO: J3.2, U2.25 (SWD)
/MCU/USB_BOOT: JP1.1 (A), R1.2
/MCU/USB_N: J2.A7 (D-), J2.B7 (D-), R3.2
/MCU/USB_P: J2.A6 (D+), J2.B6 (D+), R2.2
/MCU/XIN: C6.1, U2.20 (XIN), Y1.1
/MCU/XOUT: R6.1, U2.21 (XOUT)
/MIDI_OUT1: U2.41 (GPIO29_ADC3); also elsewhere on the board
/MIDI_OUT2: U2.40 (GPIO28_ADC2); also elsewhere on the board
GND: C3.2, C4.1, C5.2, C6.2, C7.2, C8.2, C9.2, C10.2, C11.2, C12.2, C13.2, C14.2, C15.2, C16.2, C17.2, J2.A1 (GND), J2.A12 (GND), J2.B1 (GND), J2.B12 (GND), J3.4, JP1.2 (B), JP2.2 (B), U1.2 (GND), U2.19 (TESTEN), U2.57 (GND), U3.4 (GND), Y1.2, Y1.4; also elsewhere on the board
unnamed: C7.1, R6.2, Y1.3
unnamed: JP2.1 (A), R4.2, R5.2
unnamed: JP3.1 (A), R8.2, R9.2
unnamed: R7.2, U1.3 (EN)
unnamed: R3.1, U2.46 (USB_DM)
unnamed: R2.1, U2.47 (USB_DP)

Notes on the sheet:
Each close to a DVDD pin
Close to ADC_AVDD
Close to VREG_IN
Each close to an IOVDD pin
Debug
Reset
FILTERING_CAPS
CRYSTAL
PROGRAMING_CONNECTOR
USB
MEMORY
+3V3_REGULATOR
MOUNTING_HOLES
USB_MODE_SELECTOR
RP2040

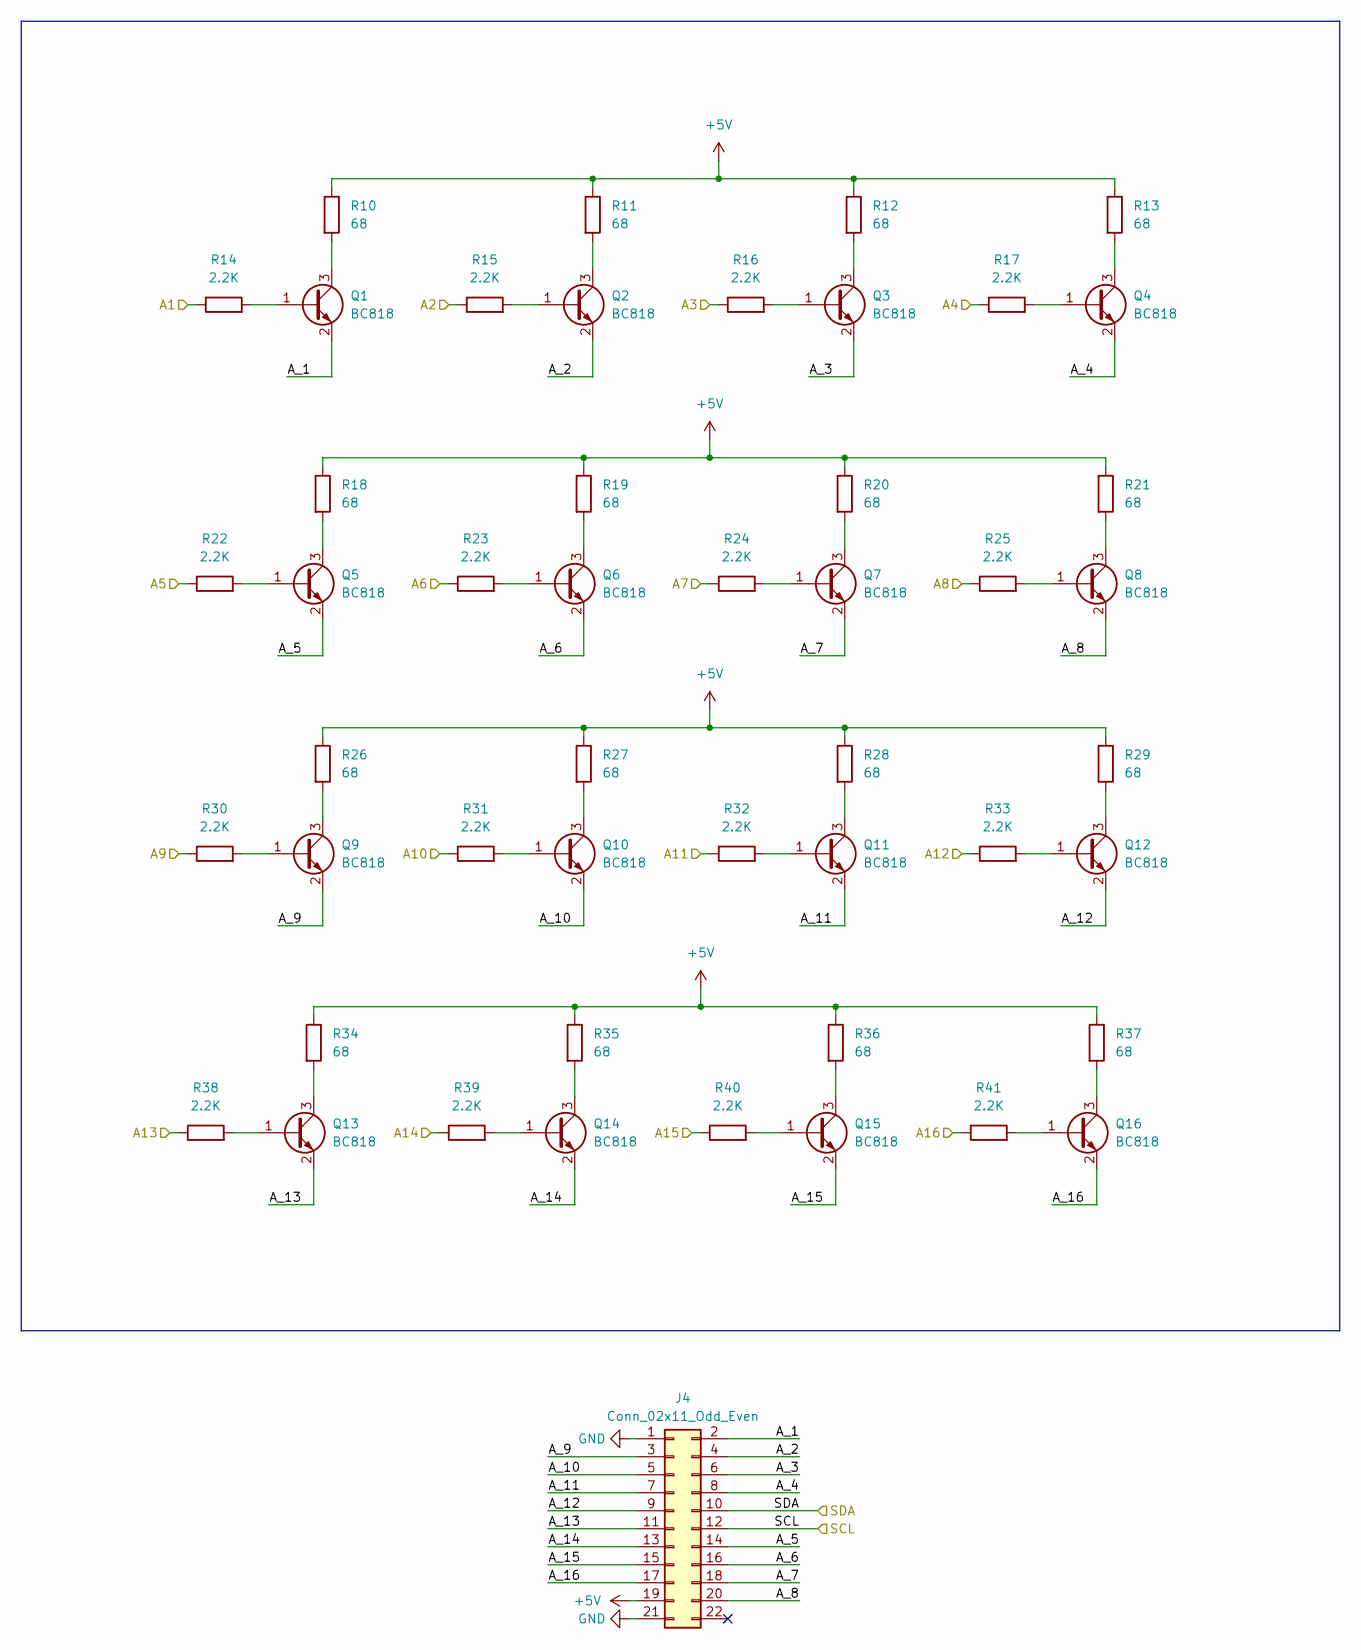
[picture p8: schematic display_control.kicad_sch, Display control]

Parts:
J4: Conn_02x11_Odd_Even; PinHeader_2x11_P2.54mm_Vertical
Q1, Q2, Q3, Q4, Q5, Q6, Q7, Q8, Q9, Q10, Q11, Q12, Q13, Q14, Q15, Q16: BC818; SOT-23
R10, R11, R12, R13, R18, R19, R20, R21, R26, R27, R28, R29, R34, R35, R36, R37: 68; R_0603_1608Metric
R14, R15, R16, R17, R22, R23, R24, R25, R30, R31, R32, R33, R38, R39, R40, R41: 2.2K; R_0603_1608Metric

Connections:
+5V: J4.19, R10.1, R11.1, R12.1, R13.1, R18.1, R19.1, R20.1, R21.1, R26.1, R27.1, R28.1, R29.1, R34.1, R35.1, R36.1, R37.1; also elsewhere on the board
/DISPLAY_CONTROL/A1: R14.1; also elsewhere on the board
/DISPLAY_CONTROL/A2: R15.1; also elsewhere on the board
/DISPLAY_CONTROL/A3: R16.1; also elsewhere on the board
/DISPLAY_CONTROL/A4: R17.1; also elsewhere on the board
/DISPLAY_CONTROL/A5: R22.1; also elsewhere on the board
/DISPLAY_CONTROL/A6: R23.1; also elsewhere on the board
/DISPLAY_CONTROL/A7: R24.1; also elsewhere on the board
/DISPLAY_CONTROL/A8: R25.1; also elsewhere on the board
/DISPLAY_CONTROL/A9: R30.1; also elsewhere on the board
/DISPLAY_CONTROL/A10: R31.1; also elsewhere on the board
/DISPLAY_CONTROL/A11: R32.1; also elsewhere on the board
/DISPLAY_CONTROL/A12: R33.1; also elsewhere on the board
/DISPLAY_CONTROL/A13: R38.1; also elsewhere on the board
/DISPLAY_CONTROL/A14: R39.1; also elsewhere on the board
/DISPLAY_CONTROL/A15: R40.1; also elsewhere on the board
/DISPLAY_CONTROL/A16: R41.1; also elsewhere on the board
/DISPLAY_CONTROL/A_1: J4.2, Q1.2 (E)
/DISPLAY_CONTROL/A_2: J4.4, Q2.2 (E)
/DISPLAY_CONTROL/A_3: J4.6, Q3.2 (E)
/DISPLAY_CONTROL/A_4: J4.8, Q4.2 (E)
/DISPLAY_CONTROL/A_5: J4.14, Q5.2 (E)
/DISPLAY_CONTROL/A_6: J4.16, Q6.2 (E)
/DISPLAY_CONTROL/A_7: J4.18, Q7.2 (E)
/DISPLAY_CONTROL/A_8: J4.20, Q8.2 (E)
/DISPLAY_CONTROL/A_9: J4.3, Q9.2 (E)
/DISPLAY_CONTROL/A_10: J4.5, Q10.2 (E)
/DISPLAY_CONTROL/A_11: J4.7, Q11.2 (E)
/DISPLAY_CONTROL/A_12: J4.9, Q12.2 (E)
/DISPLAY_CONTROL/A_13: J4.11, Q13.2 (E)
/DISPLAY_CONTROL/A_14: J4.13, Q14.2 (E)
/DISPLAY_CONTROL/A_15: J4.15, Q15.2 (E)
/DISPLAY_CONTROL/A_16: J4.17, Q16.2 (E)
/DISPLAY_CONTROL/SCL: J4.12; also elsewhere on the board
/DISPLAY_CONTROL/SDA: J4.10; also elsewhere on the board
GND: J4.1, J4.21; also elsewhere on the board
unnamed: Q1.1 (B), R14.2
unnamed: Q1.3 (C), R10.2
unnamed: Q2.1 (B), R15.2
unnamed: Q2.3 (C), R11.2
unnamed: Q3.1 (B), R16.2
unnamed: Q3.3 (C), R12.2
unnamed: Q4.1 (B), R17.2
unnamed: Q4.3 (C), R13.2
unnamed: Q5.1 (B), R22.2
unnamed: Q5.3 (C), R18.2
unnamed: Q6.1 (B), R23.2
unnamed: Q6.3 (C), R19.2
unnamed: Q7.1 (B), R24.2
unnamed: Q7.3 (C), R20.2
unnamed: Q8.1 (B), R25.2
unnamed: Q8.3 (C), R21.2
unnamed: Q9.1 (B), R30.2
unnamed: Q9.3 (C), R26.2
unnamed: Q10.1 (B), R31.2
unnamed: Q10.3 (C), R27.2
unnamed: Q11.1 (B), R32.2
unnamed: Q11.3 (C), R28.2
unnamed: Q12.1 (B), R33.2
unnamed: Q12.3 (C), R29.2
unnamed: Q13.1 (B), R38.2
unnamed: Q13.3 (C), R34.2
unnamed: Q14.1 (B), R39.2
unnamed: Q14.3 (C), R35.2
unnamed: Q15.1 (B), R40.2
unnamed: Q15.3 (C), R36.2
unnamed: Q16.1 (B), R41.2
unnamed: Q16.3 (C), R37.2

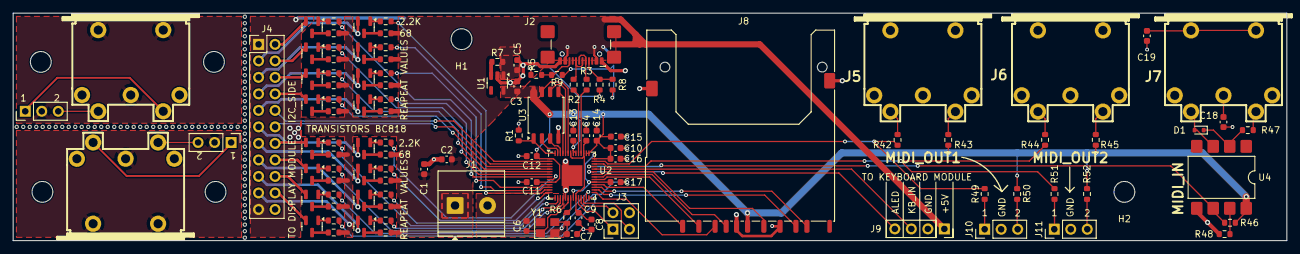
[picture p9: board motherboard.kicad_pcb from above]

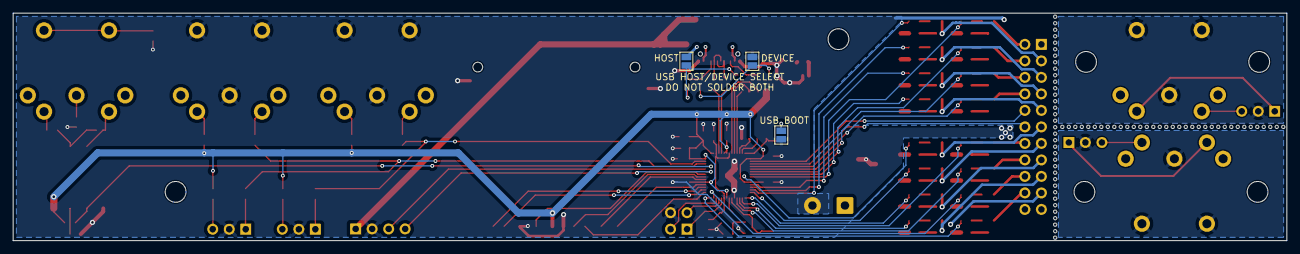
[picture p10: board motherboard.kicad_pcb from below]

Board: 2 copper layers, 196.0 x 35.0 mm, 117 parts (3 on the bottom side), 124 nets.

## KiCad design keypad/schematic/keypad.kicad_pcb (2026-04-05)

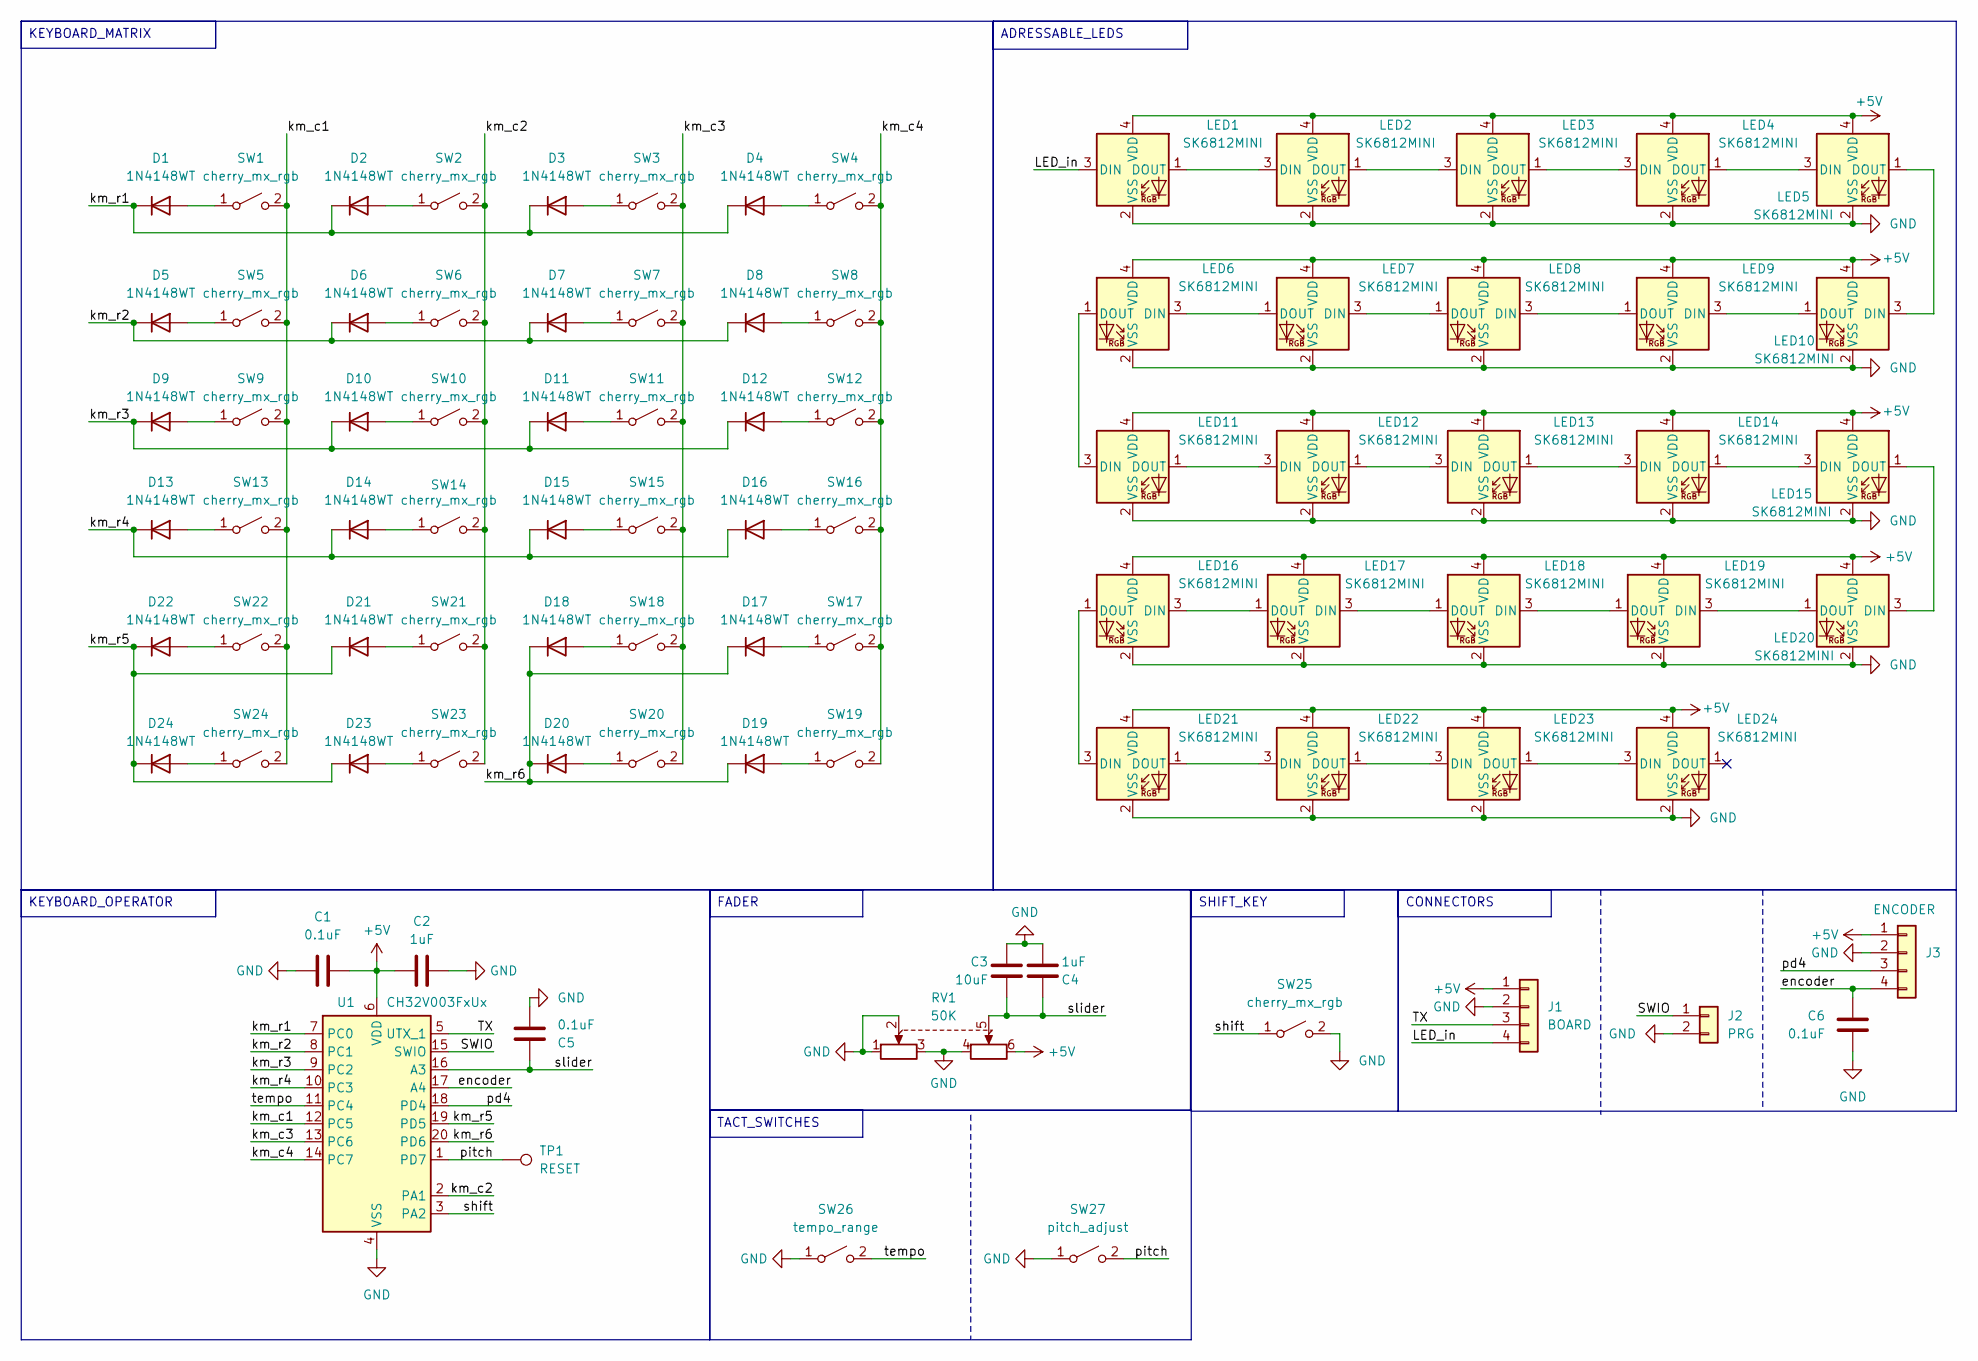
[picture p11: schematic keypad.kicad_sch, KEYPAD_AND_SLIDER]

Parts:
C1, C5, C6: 0.1uF; C_0603_1608Metric
C2, C4: 1uF; C_0603_1608Metric
C3: 10uF; C_0603_1608Metric
D1, D2, D3, D4, D5, D6, D7, D8, D9, D10, D11, D12, D13, D14, D15, D16, D17, D18, D19, D20, D21, D22, D23, D24: 1N4148WT; D_SOD-523
J1: BOARD; PinHeader_1x04_P2.54mm_Horizontal; Part Number 1-0401FBV0T
J2: PRG; PinHeader_1x02_P2.54mm_Vertical; Part Number 1-0201FBV0T
J3: ENCODER; PinHeader_1x04_P2.54mm_Vertical; Part Number 1-0401FBV0T
LED1, LED2, LED3, LED4, LED5, LED6, LED7, LED8, LED9, LED10, LED11, LED12, LED13, LED14, LED15, LED16, LED17, LED18, LED19, LED20, LED21, LED22, LED23, LED24: SK6812MINI; SK6812-MINI-E
RV1: 50K; 75mm_slide_pot
SW1, SW2, SW3, SW4, SW5, SW6, SW7, SW8, SW9, SW10, SW11, SW12, SW13, SW14, SW15, SW16, SW17, SW18, SW19, SW20, SW21, SW22, SW23, SW24: cherry_mx_rgb; SW_Hotswap_Kailh_MX_1.00u
SW25: cherry_mx_rgb; SW_Hotswap_Kailh_MX_2.00u
SW26: tempo_range; tact_switch
SW27: pitch_adjust; tact_switch
TP1: RESET
U1: CH32V003FxUx; QFN-20-1EP_3x3mm_P0.4mm_EP1.65x1.65mm

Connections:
+5V: C1.2, C2.2, J1.1, J3.1, LED1.4 (VDD), LED2.4 (VDD), LED3.4 (VDD), LED4.4 (VDD), LED5.4 (VDD), LED6.4 (VDD), LED7.4 (VDD), LED8.4 (VDD), LED9.4 (VDD), LED10.4 (VDD), LED11.4 (VDD), LED12.4 (VDD), LED13.4 (VDD), LED14.4 (VDD), LED15.4 (VDD), LED16.4 (VDD), LED17.4 (VDD), LED18.4 (VDD), LED19.4 (VDD), LED20.4 (VDD), LED21.4 (VDD), LED22.4 (VDD), LED23.4 (VDD), LED24.4 (VDD), RV1.6, U1.6 (VDD)
/LED_in: J1.4, LED1.3 (DIN)
/SWIO: J2.1, U1.15 (SWIO)
/TX: J1.3, U1.5 (UTX_1)
/encoder: C6.2, J3.4, U1.17 (A4)
/km_c1: SW1.2 (B), SW5.2 (B), SW9.2 (B), SW13.2 (B), SW22.2 (B), SW24.2 (B), U1.12 (PC5)
/km_c2: SW2.2 (B), SW6.2 (B), SW10.2 (B), SW14.2 (B), SW21.2 (B), SW23.2 (B), U1.2 (PA1)
/km_c3: SW3.2 (B), SW7.2 (B), SW11.2 (B), SW15.2 (B), SW18.2 (B), SW20.2 (B), U1.13 (PC6)
/km_c4: SW4.2 (B), SW8.2 (B), SW12.2 (B), SW16.2 (B), SW17.2 (B), SW19.2 (B), U1.14 (PC7)
/km_r1: D1.1 (K), D2.1 (K), D3.1 (K), D4.1 (K), U1.7 (PC0)
/km_r2: D5.1 (K), D6.1 (K), D7.1 (K), D8.1 (K), U1.8 (PC1)
/km_r3: D9.1 (K), D10.1 (K), D11.1 (K), D12.1 (K), U1.9 (PC2)
/km_r4: D13.1 (K), D14.1 (K), D15.1 (K), D16.1 (K), U1.10 (PC3)
/km_r5: D21.1 (K), D22.1 (K), D23.1 (K), D24.1 (K), U1.19 (PD5)
/km_r6: D17.1 (K), D18.1 (K), D19.1 (K), D20.1 (K), U1.20 (PD6)
/pd4: J3.3, U1.18 (PD4)
/pitch: SW27.2 (B), TP1.1, U1.1 (PD7)
/shift: SW25.1 (A), U1.3 (PA2)
/slider: C3.2, C4.1, C5.2, RV1.5, U1.16 (A3)
/tempo: SW26.2 (B), U1.11 (PC4)
GND: C1.1, C2.1, C3.1, C4.2, C5.1, C6.1, J1.2, J2.2, J3.2, LED1.2 (VSS), LED2.2 (VSS), LED3.2 (VSS), LED4.2 (VSS), LED5.2 (VSS), LED6.2 (VSS), LED7.2 (VSS), LED8.2 (VSS), LED9.2 (VSS), LED10.2 (VSS), LED11.2 (VSS), LED12.2 (VSS), LED13.2 (VSS), LED14.2 (VSS), LED15.2 (VSS), LED16.2 (VSS), LED17.2 (VSS), LED18.2 (VSS), LED19.2 (VSS), LED20.2 (VSS), LED21.2 (VSS), LED22.2 (VSS), LED23.2 (VSS), LED24.2 (VSS), RV1.1, RV1.2, RV1.3, RV1.4, SW25.2 (B), SW26.1 (A), SW27.1 (A), U1.4 (VSS), U1.21 (VSS)
unnamed: D1.2 (A), SW1.1 (A)
unnamed: D2.2 (A), SW2.1 (A)
unnamed: D3.2 (A), SW3.1 (A)
unnamed: D4.2 (A), SW4.1 (A)
unnamed: D5.2 (A), SW5.1 (A)
unnamed: D6.2 (A), SW6.1 (A)
unnamed: D7.2 (A), SW7.1 (A)
unnamed: D8.2 (A), SW8.1 (A)
unnamed: D9.2 (A), SW9.1 (A)
unnamed: D10.2 (A), SW10.1 (A)
unnamed: D11.2 (A), SW11.1 (A)
unnamed: D12.2 (A), SW12.1 (A)
unnamed: D13.2 (A), SW13.1 (A)
unnamed: D14.2 (A), SW14.1 (A)
unnamed: D15.2 (A), SW15.1 (A)
unnamed: D16.2 (A), SW16.1 (A)
unnamed: D17.2 (A), SW17.1 (A)
unnamed: D18.2 (A), SW18.1 (A)
unnamed: D19.2 (A), SW19.1 (A)
unnamed: D20.2 (A), SW20.1 (A)
unnamed: D21.2 (A), SW21.1 (A)
unnamed: D22.2 (A), SW22.1 (A)
unnamed: D23.2 (A), SW23.1 (A)
unnamed: D24.2 (A), SW24.1 (A)
unnamed: LED1.1 (DOUT), LED2.3 (DIN)
unnamed: LED2.1 (DOUT), LED3.3 (DIN)
unnamed: LED3.1 (DOUT), LED4.3 (DIN)
unnamed: LED4.1 (DOUT), LED5.3 (DIN)
unnamed: LED6.3 (DIN), LED7.1 (DOUT)
unnamed: LED7.3 (DIN), LED8.1 (DOUT)
unnamed: LED8.3 (DIN), LED9.1 (DOUT)
unnamed: LED5.1 (DOUT), LED10.3 (DIN)
unnamed: LED9.3 (DIN), LED10.1 (DOUT)
unnamed: LED6.1 (DOUT), LED11.3 (DIN)
unnamed: LED11.1 (DOUT), LED12.3 (DIN)
unnamed: LED12.1 (DOUT), LED13.3 (DIN)
unnamed: LED13.1 (DOUT), LED14.3 (DIN)
unnamed: LED14.1 (DOUT), LED15.3 (DIN)
unnamed: LED15.1 (DOUT), LED20.3 (DIN)
unnamed: LED16.3 (DIN), LED17.1 (DOUT)
unnamed: LED16.1 (DOUT), LED21.3 (DIN)
unnamed: LED17.3 (DIN), LED18.1 (DOUT)
unnamed: LED18.3 (DIN), LED19.1 (DOUT)
unnamed: LED19.3 (DIN), LED20.1 (DOUT)
unnamed: LED21.1 (DOUT), LED22.3 (DIN)
unnamed: LED22.1 (DOUT), LED23.3 (DIN)
unnamed: LED23.1 (DOUT), LED24.3 (DIN)

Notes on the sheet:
CONNECTORS
TACT_SWITCHES
SHIFT_KEY
FADER
KEYBOARD_MATRIX
ADRESSABLE_LEDS
KEYBOARD_OPERATOR

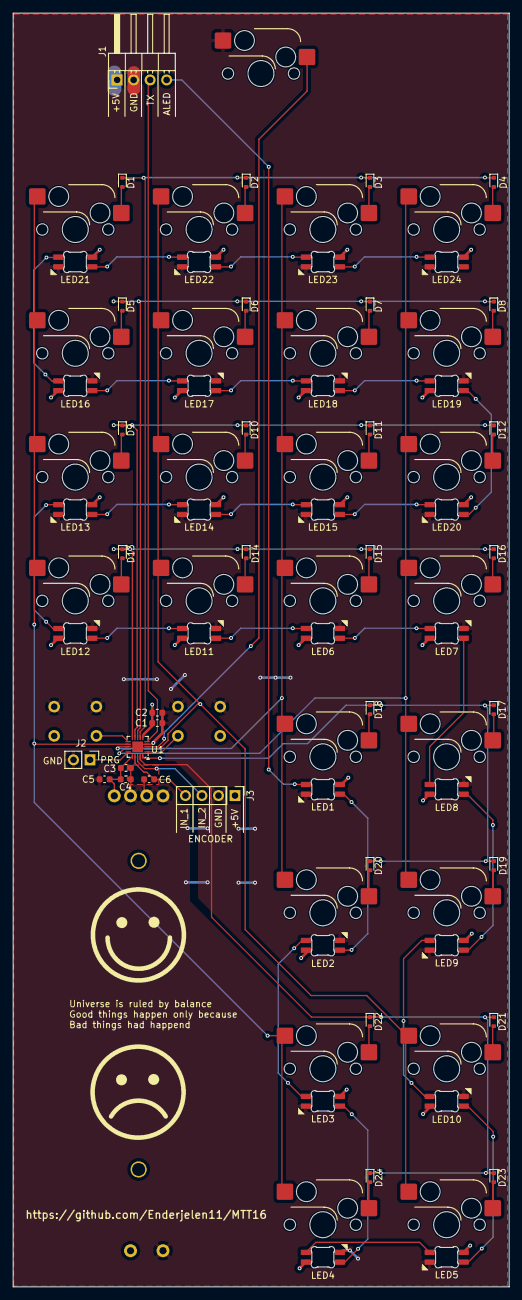
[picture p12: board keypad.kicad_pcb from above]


Board: 2 copper layers, 76.3 x 196.0 mm, 86 parts (28 on the bottom side), 68 nets.

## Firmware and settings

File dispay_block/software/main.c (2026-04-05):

/**
 * Sequential segment driver for CH32V003
 * Driven via EXTI interrupt on PC[INTERRUPT_PIN] (both edges)
 * Cycles through "SEGMENTS_TOTAL"" total segments in blocks of "SEGMENTS_ON_BOARD" per board
 */

#include "../../CH32V003_TRUE_MINIMAL/ch32v003.h"
#include <stdint.h>

#ifndef BLOCK_NUMBER
#define BLOCK_NUMBER (0)
#endif

#define SEGMENTS_ON_BOARD (16)
#define SEGMENTS_TOTAL (96)

#define INTERRUPT_PIN (5)
#define FALLING_EDGE_ENABLE (1)
#define RISING_EDGE_ENABLE (1)

#define RES_OFFSET ((uint8_t)(0x10))

#define SEGMENTS_ON_BOARD_LAST_RESET (SEGMENTS_ON_BOARD + 1)
#define DO_NOTHING_BSHR (0)

typedef struct {
    volatile uint32_t* setPort;
    volatile uint32_t setPin;
    volatile uint32_t* resetPort;
    volatile uint32_t resetPin;
} preperedBSHR_t;


static const preperedBSHR_t gpioSeq[SEGMENTS_ON_BOARD_LAST_RESET] = {
  { .setPort = &GPIOD_BSHR, .setPin = PIN(5), .resetPort = &GPIOC_BSHR, .resetPin = DO_NOTHING_BSHR  },
  { .setPort = &GPIOA_BSHR, .setPin = PIN(1), .resetPort = &GPIOD_BSHR, .resetPin = PIN(5) << RES_OFFSET },
  { .setPort = &GPIOD_BSHR, .setPin = PIN(0), .resetPort = &GPIOA_BSHR, .resetPin = PIN(1) << RES_OFFSET },
  { .setPort = &GPIOC_BSHR, .setPin = PIN(0), .resetPort = &GPIOD_BSHR, .resetPin = PIN(0) << RES_OFFSET },
  { .setPort = &GPIOD_BSHR, .setPin = PIN(6), .resetPort = &GPIOC_BSHR, .resetPin = PIN(0) << RES_OFFSET },
  { .setPort = &GPIOD_BSHR, .setPin = PIN(7), .resetPort = &GPIOD_BSHR, .resetPin = PIN(6) << RES_OFFSET },
  { .setPort = &GPIOA_BSHR, .setPin = PIN(2), .resetPort = &GPIOD_BSHR, .resetPin = PIN(7) << RES_OFFSET },
  { .setPort = &GPIOC_BSHR, .setPin = PIN(1), .resetPort = &GPIOA_BSHR, .resetPin = PIN(2) << RES_OFFSET },
  { .setPort = &GPIOD_BSHR, .setPin = PIN(4), .resetPort = &GPIOC_BSHR, .resetPin = PIN(1) << RES_OFFSET },
  { .setPort = &GPIOD_BSHR, .setPin = PIN(1), .resetPort = &GPIOD_BSHR, .resetPin = PIN(4) << RES_OFFSET },
  { .setPort = &GPIOC_BSHR, .setPin = PIN(4), .resetPort = &GPIOD_BSHR, .resetPin = PIN(1) << RES_OFFSET },
  { .setPort = &GPIOC_BSHR, .setPin = PIN(2), .resetPort = &GPIOC_BSHR, .resetPin = PIN(4) << RES_OFFSET },
  { .setPort = &GPIOD_BSHR, .setPin = PIN(3), .resetPort = &GPIOC_BSHR, .resetPin = PIN(2) << RES_OFFSET },
  { .setPort = &GPIOD_BSHR, .setPin = PIN(2), .resetPort = &GPIOD_BSHR, .resetPin = PIN(3) << RES_OFFSET },
  { .setPort = &GPIOC_BSHR, .setPin = PIN(7), .resetPort = &GPIOD_BSHR, .resetPin = PIN(2) << RES_OFFSET },
  { .setPort = &GPIOC_BSHR, .setPin = PIN(3), .resetPort = &GPIOC_BSHR, .resetPin = PIN(7) << RES_OFFSET },
  { .setPort = &GPIOC_BSHR, .setPin = DO_NOTHING_BSHR , .resetPort = &GPIOC_BSHR, .resetPin = PIN(3) << RES_OFFSET }
};

volatile uint8_t segmentCtr;

// ISR triggered on both edges of PC5.
// Advances segment sequence and updates GPIO outputs atomically.
void EXTI7_0_IRQHandler(void) __attribute__((interrupt("machine")));
void EXTI7_0_IRQHandler(void)
{
  register const preperedBSHR_t* seq = &gpioSeq[segmentCtr];

    if (segmentCtr < SEGMENTS_ON_BOARD) {
      *(seq->resetPort) = seq->resetPin;
      *(seq->setPort)   = seq->setPin;
    } else if (segmentCtr == SEGMENTS_ON_BOARD) {
      *(seq->resetPort) = seq->resetPin;
    }
    segmentCtr++;

    if (segmentCtr >= SEGMENTS_TOTAL){
      segmentCtr = 0;
    }
    EXTI_CLEAR(INTERRUPT_PIN);
}



int main(void)
{
    RCC_ENABLE_ALL_GPIO();
    RCC_APB2PCENR |= RCC_AFIOEN;

    GPIOA_CONFIG(0x07, GPIO_MODE_OUT_PP_50MHZ);
    GPIOC_CONFIG(0x9F, GPIO_MODE_OUT_PP_50MHZ);
    GPIOD_CONFIG(0xFF, GPIO_MODE_OUT_PP_50MHZ);

    GPIOC_CONFIG(PIN(INTERRUPT_PIN), GPIO_MODE_IN_PUPD);
    GPIOC_BSHR = PIN(INTERRUPT_PIN); // Pull-up

    segmentCtr = BLOCK_NUMBER * SEGMENTS_ON_BOARD;

    SETUP_EXTI_PIN(INTERRUPT_PIN, AFIO_EXTICR_PC, FALLING_EDGE_ENABLE , RISING_EDGE_ENABLE , EXTI7_0_IRQn);
    ENABLE_GLOBAL_IRQS();

    while (1) {
    }
}

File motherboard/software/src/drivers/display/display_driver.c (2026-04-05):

#include "display_driver.h"
#include "pico/stdlib.h"

#define displayInterruptPin (1)
#define DELIMETER_UP_PIN (6)
#define DELIMETER_LOW_PIN (5)

static const uint8_t segLeftPins[7] = {7, 11, 8, 2, 3, 13, 15};
static const uint8_t segRightPins[7] = {10, 9, 14, 17, 16, 4, 12};

static bool interruptFlipFlop = false;

void display_driver_init(void) {
    gpio_init(DELIMETER_UP_PIN);
    gpio_set_dir(DELIMETER_UP_PIN, GPIO_OUT);
    gpio_init(DELIMETER_LOW_PIN);
    gpio_set_dir(DELIMETER_LOW_PIN, GPIO_OUT);
    gpio_init(displayInterruptPin);
    gpio_set_dir(displayInterruptPin, GPIO_OUT);

    for (int i = 0; i < 7; i++) {
        gpio_init(segLeftPins[i]);
        gpio_set_dir(segLeftPins[i], GPIO_OUT);
        gpio_init(segRightPins[i]);
        gpio_set_dir(segRightPins[i], GPIO_OUT);
    }
}

void display_driver_set_segments(uint8_t left_mask, uint8_t right_mask) {
    for (int i = 0; i < 7; i++) {
        gpio_put(segLeftPins[i], (left_mask >> i) & 1);
        gpio_put(segRightPins[i], (right_mask >> i) & 1);
    }
}

void display_driver_set_delimiters(bool upper, bool lower) {
    gpio_put(DELIMETER_UP_PIN, upper);
    gpio_put(DELIMETER_LOW_PIN, lower);
}

void display_driver_clear(void) {
    display_driver_set_delimiters(false, false);
    display_driver_set_segments(0, 0);
}

void display_driver_next_digit(void) {
    gpio_put(displayInterruptPin, interruptFlipFlop);
    interruptFlipFlop = !interruptFlipFlop;
}

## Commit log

2026-04-05 chore: initial commit with README and KiCad ignore
2026-04-05 hw: add initial display schematic
    [char_block.kicad_sch, dispay_block.kicad_pcb, dispay_block.kicad_sch]
2026-04-05 hw: annotate schematics and add capacitor footprints
    [char_block.kicad_sch, dispay_block.kicad_sch]
2026-04-05 chore: add KiCad lock files to gitignore
2026-04-05 hw: add display segment schematic and PCB v1
    [char_block.kicad_sch, dispay_block.kicad_pcb, dispay_block.kicad_sch]
2026-04-05 hw: add footprint library for MIDI, sliders, and SK6812
2026-04-05 hw: add slider potentiometer footprint
2026-04-05 fix(hw): correct SK6812 LED footprint
2026-04-05 hw: add tact switch footprint
2026-04-05 fix(hw): adjust silkscreen for JLCPCB capabilities
2026-04-05 hw: add keypad schematic
    [keypad.kicad_pcb, keypad.kicad_sch]
2026-04-05 fix(hw): correct display block silkscreen
    [dispay_block.kicad_pcb]
2026-04-05 fix(hw): update keypad silkscreen
    [keypad.kicad_pcb]
2026-04-05 hw: add RP2350 footprint
2026-04-05 hw: revise display design and fix wrong footprint
    [char_block.kicad_sch, dispay_block.kicad_pcb, dispay_block.kicad_sch]
2026-04-05 chore(hw): migrate keypad to KiCad v9
    [keypad.kicad_pcb, keypad.kicad_sch]
2026-04-05 hw: add MIDI DIN symbol and update footprint
2026-04-05 chore(hw): migrate display block to KiCad v9
2026-04-05 hw: add mouse bite footprint and fix MIDI DIN
2026-04-05 hw: add encoder support to keypad
    [keypad.kicad_pcb, keypad.kicad_sch]
2026-04-05 hw: add motherboard PCB
    [display_control.kicad_sch, mcu.kicad_sch, motherboard.kicad_pcb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]
2026-04-05 chore: restructure project folder layout
    [char_block.kicad_sch, dispay_block.kicad_pcb, dispay_block.kicad_sch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]
2026-04-05 chore: add Pico SDK submodule
2026-04-05 fix: add parentheses to display block defines
    [main.c]
2026-04-05 feat: implement MIDI out via DMA
2026-04-05 fix: resolve PIO/DMA resource collisions
2026-04-05 refactor: restructure into layered app/services/drivers
2026-04-05 test: add temporary display driver and manager
